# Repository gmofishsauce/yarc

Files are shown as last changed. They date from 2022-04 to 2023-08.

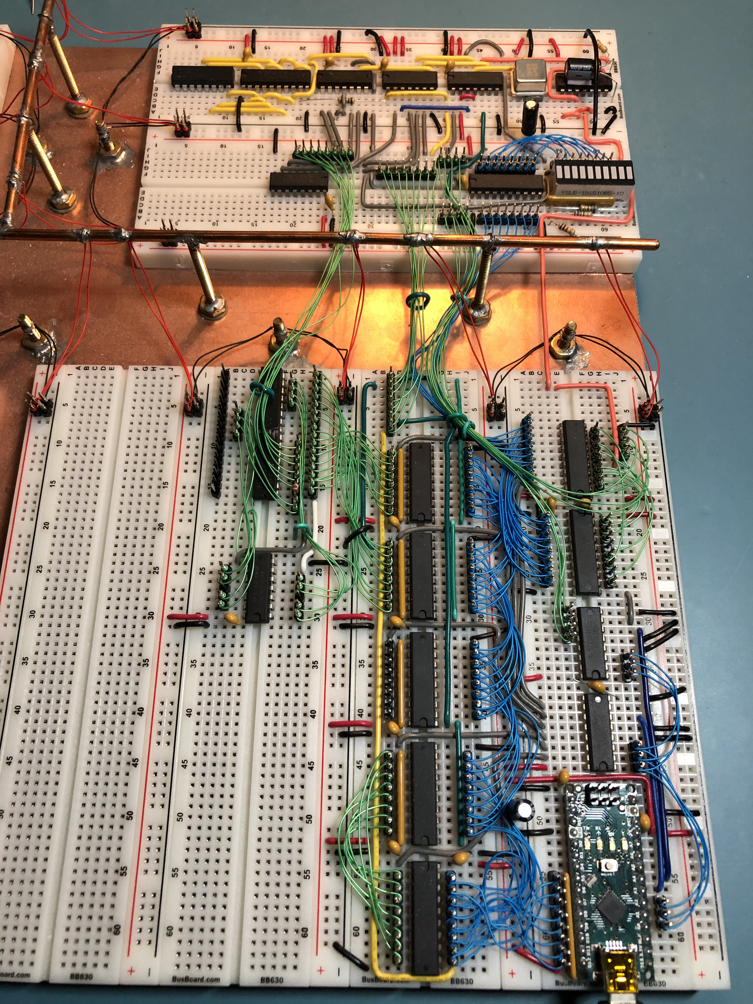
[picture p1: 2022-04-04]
img/2022-04-03/YARC-buildout-2022-03-31-2.jpg

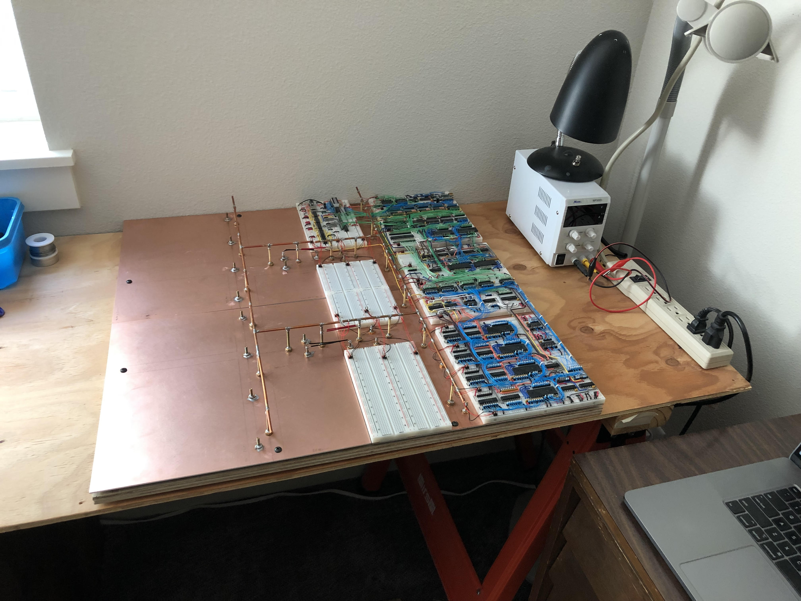
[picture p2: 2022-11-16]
img/2022-11-16/MechanicalCompleteOct13.jpeg

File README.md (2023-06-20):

# YARC - Yet Another Retro Computer

## Overview

YARC is a homebrew CPU and computer design implemented in a retro style.
Work on YARC started in April 2021. The initial concept was an 8-bit
computer with a 16-bit multiplexed address/data bus and extensive
pipelining.

In December 2021, the design changed to a 16-bit computer with separate
address and data busses, minimal pipelining, four general registers, an
8-bit-wide/2-cycle ALU, and two hardware stacks. In short, a general
register machine with specific concessions to the efficient implementation
of Charles Moore's FORTH programming language.

Most recently, I decided not to build the stack hardware and to instead
focus on developing the basic instruction set using two of the four
registers for PC and SP. I plan to write a translator for a small subset
of web assembler to YARC machine language (an "AoT" in their terminology,
ahead-of-time compiler). This will allow me to program the YARC in a small
subset any language that can target WASM--like Gnu C or Golang--rather
than confining YARC programming to the Forth language.

YARC is permanently tethered to a host computer (Mac) through a module
called the "Downloader" (a misnomer, because communication is supported
in both directions between host and YARC). The Downloader is based on a
modern microprocessor (Arduino Nano) which implements serial over USB.

The YARC itself is built from 74HC-series CMOS parts, with a few
out-of-period extensions like 8kx8 static CMOS RAMs.

## NRR - It's Not Really Retro

YARC's architecture resembles the [Data General Nova](https://en.wikipedia.org/wiki/Data_General_Nova) minicomputer. The Nova was introduced in 1969. YARC, like Nova, is mostly built from 7400-series components.

But the YARC is _nothing_ like a 1970s minicomputer. Why not? Let me count the ways...

* **Sophisticated open source design software.** In 1969, "design software" meant a sharp pencil, a [plastic template](https://www.amazon.com/Alvin-TD1279-Electric-Electronic-Template/dp/B000KNLR4A/ref=asc_df_B000KNLR4A/), and an angled table. Now, it means [KiCad](https://www.kicad.org/).
* **Highly integrated, sub-100ns static RAMs.** In 1969, semiconductor memory hadn't happened yet. YARC relies on 8k x 8 static CMOS RAMs with 55ns access times - each chip contains more transistors than an _entire_ Data General Nova. And the original Nova, with core memory, had a 5-microsecond cycle time - about 10x slower than YARC can likely achieve.
* **Universal knowledge base.** In 1969, knowledge about computer design was in the hands of a few experts. Today, a quick search can bring you [this](https://www.godevtool.com/GoasmHelp/usflags.htm) or [this](https://www.righto.com/2013/09/the-z-80-has-4-bit-alu-heres-how-it.html).
* **These aren't the 7400 series components you're looking for.** YARC is built with 74HC-series components. These have better noise margins, controlled edge rates, and far lower power consumption than traditional 7400-series TTL. It's fair to say the 74HC-series wasn't introduced until it was already obsolete!

## What's here?

### [ard](https://github.com/gmofishsauce/yarc/tree/main/ard/yarc_fw) - Arduino code for YARC downloader

Nano IDE (v2.X) project holding C++ code for the Arduino that implements
the "Downloader" (which should be renamed to "System Interface" or something).

### [doc](https://github.com/gmofishsauce/yarc/tree/main/doc) - YARC documentation

Engineering documentation for YARC. No "user documentation" is planned,
but some of the documentation is tersely user-oriented, such as the
document that describes the assembly language.

### [ftz](https://github.com/gmofishsauce/yarc/tree/main/ftz) - Fritz sketches for YARC.

Fritzing is a useful sketchpad for breadboard-based designs but it's
incredibly quirky.  No guarantees anyone will be able to load these
sketches, not to mention modify them.

Fritzing really, *really* wants everything in "``~/Documents/Fritzing``" on
Mac, and on Mac, setting $HOME does not affect the expansion of tilde.
But I found that making "``~/Documents/Fritzing``" a symlink into this repo
works.

### [img](https://github.com/gmofishsauce/yarc/tree/main/img) - Eye candy

Images of Fritzing sketches, KiCad schematics, and the implementation
itself. Allows the schematics and layouts to examined without
installing the apps (KiCad and Fritzing).

### [ki](https://github.com/gmofishsauce/yarc/tree/main/ki) - KiCad schematics

I started using KiCad just after 6.0 came out so if you use an earlier
version, you'll have to upgrade to load the sketches.

### [yarc](https://github.com/gmofishsauce/yarc/tree/main/yarc) - Host software

All the host software is written in Go and tested on darwin-amd64
(Intel-based Mac, not M1) only. The host software is contained in a Cobra
CLI defined here.

### [yasm](https://github.com/gmofishsauce/yarc/tree/main/yasm) - YARC microassembler and assembler source code

The YARC assembler supports definition of the assembly language
mnemonics within the language along with the microcode for each
instruction. So the code in this directory defines the YARC instruction
set.

The assembler itself is invoked by `yarc asm ...` in the host software.

## Problems with YARC

YARC is my first-ever large digital design. It has many issues.

### Messy Control Circuitry

The microcode (writable control store) and ALU (arithmetic/logical unit) of YARC are implemented with RAMs instead of the more common EEROM/EPROM technologies. The RAMs must be "downloaded" with content from the host (Mac) through the Arduino ("downloader") before YARC can start.

This is cool, as I can fundamentally change YARC's behavior without popping ROMs in and out of circuit. But it greatly complicated the design, requiring a "back bus" for writes to ALU and Microcode RAM, additional transceivers, and control circuitry. I made matters much worse by failing to think through the control circuitry in a unified way, instead constructing a bunch of special-purpose control registers.

### Floorplanning Issues

YARC is implemented on 32 large solderless breadboards mounted to four 1' square copper clad boards. At 2' by 2', it has the potential for very long wire runs. I made this situation far worse than necessary by putting controls distribution in the center rather than centralizing data buses and bus transceivers and bringing control signals in from the edges.

### Write timing

Both the main memory RAMs and the 74HC670 devices used for the dual-ported general registers suffer from issues if their address inputs change while their write-enable signals are active (low in both cases). I conceived each bus cycle as "outputs are enabled during first half of clock with clock high, enables go low for second half of clock, and writes are latched at rising edge". Unfortunately, transceivers enables are "enables", and also drive address lines; so their settling time overlaps with the write signal going low. I had to implement delay lines for write clocks in two places.

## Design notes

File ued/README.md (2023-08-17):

# Microcode editor

The original microcode editor is in first.htm. It "works".

A prototype "improved" microcode editor is in ucode.{htm,js,css}. It's not ready.

## Usage

Open the `.htm` file directly in the browser. The page does not use the network and does not write any local state. As you set the controls, the text at the bottom of the screen changes. When you are satisfied, copy and paste that text into Arduino C code or yasm source code. Refresh the page to reset.

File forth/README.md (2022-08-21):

# Forth

The goal of YARC is to eventually bootstrap Forth on the YARC,
using the approach called "subroutine threaded code with in-line
expansion" but with 30 or more basic Forth primitives implemented
as machine instructions, i.e. in microcode.

This is similar to https://www.jhuapl.edu/Content/techdigest/pdf/V10-N03/10-03-Lee.pdf.

A beautifully-commented Forth implementation for x86 Linux can be
found in the jonesforth directory. Of course I won't need to define
the primitives (DUP, SWAP, and about 30 others) in assembly language,
because they'll be single machine instructions implemented in yarc/yasm.
And I won't need e.g. **next** as a primitive either; it will simply
be a YARC instruction fetch, as the Forth "inner interpreter" will be
the instruction fetch hardware of YARC.

But Jonesforth will guide the set of words that have to be implemented
in assembler (there will be some, such as the words that handle console input)
and the Forth file may be consumable directly if I can fully duplicate the
functionality of the jonesforth.s file in YARC.

Nevertheless, YARC will remain a general register computer with a
standard assembly language and have only certain concessions to the
Forth implementation. The concessions include the two hardware stack
and the microcoded primitives.

YARC is similar to http://users.ece.cmu.edu/~koopman/stack_computers/sec4_2.html.

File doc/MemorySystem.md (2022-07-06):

# YARC 30k RAM

## System Context

The YARC data and address busses have 16 wires. There are 16 data bits and
15 address bits. The high-order "bit" on the address bus is the READ/WRITE#
signal. The only other global control signal is the clock; unlike other
parts of YARC, the memory system's behavior is does not vary between init
and runtime (i.e. the YARC/NANO# signal plays no part in memory control).

The 32k address space is divided into 30k bytes of memory and 2k bytes of
I/O space. The memory is implemented with 4 8kx8 CMOS static RAMs. These
are not "period" parts ("It's Not Really Retro!"). Each RAM contains about
400,000 transistors. Such parts became available in the 90s as geometries
fell below 1 micron (1000nm).

The high-order address bit is ignored, so the address 0x8000 folds back
to address 0, 0x8001 to 1, ... and 0xFFFF to 0x7FFF.

Control logic is implemented using 74HC-series MSI like the rest of the YARC
design. 

## Functionality

Memory is both byte and word addressable. Three types of memory cycles are
supported: byte on even address, byte on odd address, and word (16 bits)
on even address. The behavior of word cycle on odd address is undefined.

Memory responds to the addresses 0x0000 through 0x77FF ("30k - 1"). Addresses
from 0x7800 to 0x7FFF do not select any of the RAM chips nor open the
memory bus transceivers. If the I/O subsystem doesn't decode the address,
the data bus will be undriven. The resulting behavior is undefined but in
practice the implementation returns 0xFFFF for reads and discards writes.

## Implementation

Refer to the KiCad schematic title "YARC Memory" or the equivalent image
in the **img** directory.

Fundamental control signals are developed by the NAND gate U14A and the
decoder U22A. These are found at coordinates B1 in the schematic. The NAND
gate's output is `RAM/IO#`. This is low for I/O addresses (0x7800 through
0x7FFF) and high for memory addresses (0x0000 through 0x77FF).

Decoding this signal with the `READ/WRITE#` line (`SYSBUS:15`) (section B1)
produces the four signals `MEMRD#`, `MEMWR#`, `IORD#`, and `IOWR#`. These
are unclocked and as a result are potentially glitchy.

The IO read/write signals are not used by the memory subsystem, although
`RAM/IO#` and a signal called `LOW128#` (derived from the address bus in
section C1 of the schematic) are generated on-board and routed to a decoder
in the Downloader Extension.

MEMRD# and MEMWR# are mixed with the clock to create the signals `MEMRD_CLK#`
and `MEMWR_CLK#` (section B2). These are not (supposed to be) glitchy, since
the address shold have settled before the clock goes low in the second half
of each cycle. (Normally, we don't use an overbar or `#` symbol for clock
lines; maybe we shouldn't here either.)

The clocked MEMRD and MEMWR signals form the output enable (OE#) and
write enable (WE#) signals to the RAMs. The RAM/IO# line is used for the
active-high CE2 line.

The low chip-enable is used to select the correct
RAM (or RAM pair for 16-bit operations). This the result of somewhat
complex decoding performed by half a 2-4 decoder (139) U22B and by U26,
a multiplexer, found in C2 and C3 of the schematic. The results are the
four signals `SEL_xRxB` where `x` is H for Hi or L for low. The range
refers to the address (upper or lower 16k) while the byte refers to
high byte or low byte.

The 157 is switched based on the 16-bit cycle line `MEM16#` so that
two RAMs are selected when `MEM16#` is low but only one RAM when high.
The bus transceivers, in turn, are controlled by signals derived in
D1 through D3 of the schematic. The `CROSS_EN#` signal enables the high
memory bus to low system bus when a byte cycle is performed to an odd
address. `STRAIGHT_EN#` enables high-to-high and low-to-low transceivers
for both even-addressed cycle types, byte and word.

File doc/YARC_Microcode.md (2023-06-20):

# YARC Microcode

## Overview

YARC is a homebrew 16-bit microcoded computer. When the Arduino-based control processor ("Downloader", "the Nano") enables YARC execution, one word of microcode is clocked from the writeable control store (WCS) to the microcode pipeline register "K" on each rising edge of the system clock. The value in the K register drives control lines to all parts of YARC.

The WCS and K register are are organized as four byte-wide "slices". The transceivers that connect them to the system bus are under control of the Nano only, so YARC cannot update its own control store. The Nano typically initializes the WCS by writing values transmitted from the host (Mac) computer. Microcode is authored on the Mac and transformed into download format by an assembler. The assembler allows the YARC's instructions to be defined (by authoring the microcode for each one) and then used, i.e. it is both a microcode and instruction set assembler. It is described in a separate file in this directory. The Nano can also write directly to the K register, allowing it to control all parts of YARC for testing.

YARC has 16-bit instructions. The current instruction is stored in the dedicated register IR which is made up of high and low bytes IRH and IRL. Instructions in the range 0x0000 through 0x7FFF are jumps and calls; these are not microcoded and will be described later. Microcoded instructions range from 0x8000 through 0xFFFE. The high-order bit is always 1 (in effect it selects microcoded instructions versus hard wired jumps and calls). The 7 remaining bits of IRH form address bits 12:6 of the WCS address. A six-bit synchronous binary counter forms address bits 5:0. The counter is reset to 0 when IR is loaded and only counts up. So there are 2^7 = 128 distinct opcodes, each of which may execute for up to 2^6 = 64 clock cycles.

This describes the entire microcode controller: every instruction executes 1 to 64 microcode words in order. There are no microcode branches or loops. The way conditional flow control instructions are executed is described later. 

Each 32-bit word in the WCS is called a "slot". Within a machine instruction, each slot represents one clock of execution. Each instruction must end with the microcode steps to fetch the next instruction and clock its first word into the K register, so in effect each instruction can have only 62 useful steps. Most instructions are much shorter. The 8-bit wide ALU requires two cycles to perform a 16-bit logical or arithmetic operation, so the instruction ADD R0, R1, R2 requires four clocks: ALU phase 1, ALU phase 2, FETCH, and DECODE, after which the next instruction will execute microcode from slot identified by IRH defined by whatever was FETCHed.

The large number of slots (64) available to each instruction is mostly an artifact of the unrealistically large size of available memory chips (8k x 8 being the smallest widely-available part still in production in 2022). The large number of slots will, however, allow for some interesting instructions, such as a 16-bit multiply.

## Writing Microcode

Microcode authoring is supported by a simple single-page web application found in yarc/ued/first.htm. This file is intended to be opened locally rather than served by an HTTP server. I am neither a Javascript programmer nor a web developer. The code in `ued` is mostly copied from bits and pieces found on Stack Overflow.

As the controls are used to alter the values of fields, the commentary lines at the bottom of the page will update to display the field values. These text lines can be copied and pasted into YARC assembler (yasm) source files, typically into `.set` directives. Other plausible functionality, such as pasting microcode into the page to disassemble hex to field values, has not been implemented.

## Microcode Fields

The microcode is described as a set of bitfields in the 32-bit K register. The Nano must write it in 1-byte wide slices, however, so for sanity the design tries to break up the microcode into byte-wide chunks with somewhat meaningful field groupings.

All bits that are not decoded as fields are active LOW. Multiple bit fields either reserve the "all 1s" value as no operation or are enabled by some active LOW bit. The end result is that 0xFF_FF_FF_FF implements "no operation" if executed as microcode. The Nano initializes all of microcode memory to this FF pattern during YARC power on and writes this same pattern to the K register to make the YARC "safe" (inactive).

### K[3] Register Control Word

K3 (the most significant bits of K) are the Register Control Word (RCW). Note: the RCW was previously called the Register Specifier Word (RSW) and is still called that in many places.)

This word specifies the behavior of the two ALU source busses and the ALU destination bus.

```
.bitfield src1   31:30   # contains a gr
.bitfield src2   29:27   # contains a gr (3..0) or a constant reg (7..4)
.bitfield dst    26:24   # contains a gr (3..0) or a conditional gr (7..4)
```
The src1 field (2 bits) specifies one of the four general registers. The specified src1 register also drives the address bus.

Src2 (3 bits) may be one of the four general register 0..3 or, by specifying a value in the range 4..7 may be one of the small constants -2, 1, 1, or 2. These constants support "auto increment" or "auto decrement" addressing; e.g. the instruction MOVBI (R0), +1, R2 can address memory at R0 and clock the data into R2 during the first cycle, while simultaneously performing ALU phase 1 of ADDing R0 and +1. The next cycle can perform ALU phase 2 and clock the result back to R0.

The correspondence between src2 values 4..7 and small constants is:

```
.set const_p2 4   # 4 in src2 makes the value positive 2 (p2)
.set const_p1 5   # 5 makes the value positive 1 (p1)
.set const_n2 6   # 6 makes the value negative 2 (n2)
.set const_n1 7   # 7 makes the value negative 1 (n1)
```

The dst field may specify a general register 0..3 or, by specifying a value in the range 4..7, may specify a _conditional load_. During a conditional write, four bits specify one of 16 conditions (carry set, overflow, etc.) from the ALU flags. The write occurs if the condition is satisfied, and otherwise does not occur.

Since one of the four "general" registers must act as the program counter, a microcoded ADD followed by a conditional load to the PC general register (R3) is used to implement conditional branches.

The four bits that select the branch condition are called the ALU Condition Nybble (ACN). During an ALU operation, these same four bits select one of 16 ALU operations. Both the RCW and the ACN may come from either microcode or from the instruction register (IR). The decision is made on a cycle-by-cycle basis under the control of control bits in the K[0] microcode word, described below.

Note: The register implementation can read two register and write one in each machine cycle, but the microcode programmer must not read and write the same register in any one cycle. This is due to a limitation of the components and is not detected in hardware. Because of the serendipitous decision to implement an 8-bit, 2-cycle ALU, this restriction has less impact than might be imagined. The instruction ADD R0, R1, R0 is implemented by reading R0 and R1 during the first (ALU phase 1) cycle and writing the sum to R0 at the end of the second (ALU phase 2) cycle, so it does not violate this restriction. A single-cycle like MOV (R0), R0, which would read an address from R0 and write data back to it at the end of the cycle, is forbidden.

### K[2] ALU Controls

```
.bitfield acn           23:20   # 1 of 16 alu operations
.bitfield alu_ctl       19:18   # 0=alu_phi1, 1=alu_phi2, 2=alu_in, 3=none
.bitfield alu_load_hold 17:17   # when low, clock the port 2 ALU holding register
.bitfield alu_load_flgs 16:16   # when low, clock the flags (ALU phi2 or write to flags)
```
The ALU operations (ACN described above) are defined in the instruction set document: 0 is ADD, etc. The ALU control field specifies ALU phase 1 or 2 or no operation. The value `alu_in` reverses the src2 transceivers to the data bus allowing a microcoded move the src2 holding register. This is encoded as an ALU operation to prevent combining it with either ALU phase 1 or 2 (the data would arrive too late in the cycle to allow the ALU to work). The pipeline register is "non-architectural", i.e. it is not exposed in the instruction set.

The `alu_load_hold` bit causes the ALU holding register on the src2 bus to be loaded. This must be a separate, microcode-programmer controlled bit so that the microcoder may issue ALU phase 1 with a load (for a register to register operation), or, alternatively, may do an `alu_in` cycle to load the pipeline register from memory, then an ALU phase 1 that operates on a register specified by src1 and the preloaded pipeline register.

Finally `alu_load_flgs` bit causes the flags register to be loaded. It is normally set during ALU phase 2, but would not be set for e.g. the add that updates the PC (R3) on every FETCH/DECODE. It must be set to load the flags from memory (e.g. MOV ..., F or POP F, etc.)

### K[1] Busses and Stacks

```
.bitfield sysdata_src  15:13  # 1 of 8 data bus drivers
.bitfield reg_in_mux   12:12  # register input, 1 = sysdata, 0 = alu output
.bitfield not_used     11:9   # reserved
.bitfield dst_wr_en     8:8   # enable write to GRs
```
The `sysdata_src` field identifies the subsystem that will drive the data bus in this cycle, if any. Note: the address bus is always driven by the general register selected by the src1 field.

```
# data bus drivers for memory writes
.set bus_gr    0        # general register drives bus
.set bus_sp    1        # not used (was: hardware stacks)
.set bus_ir    2        # instruction register drives bus
.set bus_f     3        # flags register drives bus
.set bus_mem   4        # memory drives bus (memory read)
.set bus_tbd_5 5        # unused
.set bus_tbd_6 6        # unused
.set bus_none  7        # "none" - permanently reserved
```
The next bit determines whether data for a register write, if any, comes from the ALU outputs or the system data bus. The next three bits are reserved. Finally, the LS bit of K1 enables writes (including conditional writes) to the general registers. If the bit is high, no write will occur. If the bit is low and the dst bits in K[3] specify a register, that register loaded. If low and dst specifies a conditional load, that register will be loaded if the condition specified by the ACN is true. The mapping of conditions to ACN values can be found in the instruction set document.

### K[0] Miscellaneous Controls

```
.bitfield rw            32    7:7   # read/write# line for all memory and I/O transfers
.bitfield m16_en        32    6:6   # enable 16-bit memory or I/O cycle (default 8 bit)
.bitfield load_ir       32    5:5   # clock the IR
.bitfield rcw_ir_uc     32    4:4   # RCW from IRL7:0 when low, from K31:24 when high
.bitfield carry_en      32    3:3   # Force carry-in low when low (for add vs adc)
.bitfield load_flgs_mux 32    2:2   # From sysdata when high else from ALU result flags
.bitfield acn_ir_uc     32    1:1   # ACN from IRH11:8 when low, from K23:30 when high
.bitfield ir0_en        32    0:0   # Force IR:0 to sysdata low when low (for jumps)

```
The MS bit specifies read or write for transfers to the memory and I/O space only; if the instruction specifies (e.g.) a load of the instruction register IR, the bit is not regarded. The `m16_en` bit enables 16-bit memory accesses; when high, all memory access are bytes. Note: byte accesses may be to any address, but 16-bit words may be read or written from even addresses only. The effect of a 16-bit access to an odd address is not defined. The error is not detected by hardware.

The `ir_clk` bit enables writes to the instruction register. It must be low during a cycle that fetches the next instruction. It could be used to support a hypothetical `execute` instruction that would execute an instruction out-of-line.

The `rcw_ir_uc` bit selects the source of the RCW, from K[3] when high else from IRL.

Review: in any given cycle, both the Register Control Word (RCW) and the ALU Condition Nybble (ACN; 12 bits total) can come from one of two places: (1) from the microcode bits in K3 and the upper bits of K2, or (2) from the IR bits 11:0. This design is an expensive compromise (3 multiplexer chips and a bunch of wires) between (1) having a relatively small number of instruction bits and (2) wanting to enable complex, multiple-step microcode instructions that may perform arithmetic. The first requires the that low byte of the instruction register be able to specify registers, and the second requires that the microcode be able to do so (since the instruction bits won't change during a complex instruction that may need to do various register and arithmetic operations).

The four low-order bits of K[0] are described in their comments.

## Jumps and Calls

The low-numbered even opcodes 0x0000 through 0x7FFE are CALL instructions that target themselves: the opcode 0x0020 is CALL 0x0020. Since instructions are 16-bit values and all 16-bit values must be read from even addresses, the odd numbers 0x0001 through 0x7FFF would not be useful as similar instructions. So the hardware maps the patterns as JUMPs (rather than CALLs) to next-lower opcode value: the opcode 0x0021 is JUMP 0x0020.

The high-order bit of IR is connected to the control line of a multiplexer. When it's 1 (instruction 0x8000 through 0xFFFF), the multiplexer gates the 7 low-order bits of IRH through as microcode address bits 12:6. When it's a 0, the multiplexer gates through a fixed pattern, which is 0b111_111X with X = 0 for calls and 1 for jumps. The effect is that all jumps and calls are transformed in the opcodes 0xFFxx and 0xFExx. Microcode at these locations pushes the PC on the stack (for calls) and then loads the instruction register into the PC, masking the low order to ensure the next fetch is from an even address. When loading the PC, bit K[0]:0 should be low to force the low order bit of the instruction, which is its own target address, to be 0.

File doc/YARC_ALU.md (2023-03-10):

# YARC ALU

## Overview

The YARC is a 16-bit retrocomputer implemented with 74HC-series CMOS versions of 1970s style components but using more modern 8k x 8 RAM chips (because 1970s RAMs have become serious collector's items). It has a 16-bit data bus, 16-bit-wide main memory, and a small 32k address space. 30k of the address space is RAM (0 - 0x77FF) and the top 2k is reserved for I/O registers.

In order to reduce part count, YARC's ALU is only 8 bits wide. Two clock cycles are required for each ALU operation, including the program counter increment following an instruction fetch.

There is lots of precedent in early computers for ALUs that are narrower than the system data bus or memory width. The Z-80 had an ALU only 4 bits wide. Digital's 12-bit PDP 8-I had a 1-bit ALU; it required 12 clock cycles for an add, a subtract, etc. The RCA 1802 microprocessor also had a 1-bit ALU and required 8 clock cycles for a byte operation. Early calculator chips generally operated on one BCD digit at a time.

This document describes the YARC ALU in detail. Refer to sheet 15 (YARC ALU) of the YARC's KiCad schematic for the wiring of the ALU buses. Refer to sheet 17 (YARC ALU Controls) for the flag logic (how the zero and carry flags are set) and to sheet 11 (YARC Flag Logic) for how the CPU flags are interpreted by conditional branch instructions.

## ALU Control

The ALU is controlled by a decoded two-bit microcode field. When the field's value is 3 (0b11), the ALU performs no operation. When 0, the ALU performs a first-cycle ("phi1") operation and when it's 1, a second-cycle ("phi2") operation. The effect of the value 2 (0b10) is explained later.

The ALU has two 16-bit input holding registers, one for each "side". The holding register on ALU port 1 is clocked on any phi1 cycle (i.e. at the start of any ALU operation). Separate bits control the loading of the holding register on ALU port 2 and loading of the ALU flags register. A separate 4-bit field selects one of 16 possible ALU operations. This field must be set to the desired operation during both phi1 and phi2. The operations are typical ALU operations (ADD, SUBTRACT, bitwise operators). They are defined in the accompanying instruction set document.

## ALU Input

The holding registers, which are shown on sheet 11 (YARC Flag Logic), are "fed" from the YARC's general registers via buses S1BUS15:0 and S2BUS15:0. The YARC has 4 16-bit general registers, one of which must be reserved as the PC. The registers support two independent reads per clock cycle. One bank feeds the S1BUS and the other bank feeds S2BUS. The registers to read are called out by separate microcode fields. The content of S1BUS is also driven to the system address bus in all cycles.

The input holding registers drive *byte wide* inputs to the ALU core called A and B. These must each supply one operand byte per cycle: the low operand bytes during phi1 and the high bytes during phi2. Thus the input registers thus act as 16:8 multiplexers. Each holding register is implemented as two 8-bit halves with separate enables. Both low bytes are enabled to the ALU "A" and "B" inputs during phi1, both high bytes during phi2.

The lower byte of both holding registers are implemented as transparent registers (like the popular 74LS373; actually CMOS 74HC573s which have nicer "straight across" pinouts). During the cycle, their outputs follow their inputs with a delay of about 25ns. At the end of the cycle, they "freeze" (latch) the value. The high byte of both holding registers is implemented with clocked D registers (HC574s). Both parts have 3-state outputs which are used to accomplish the multiplexing function.

This may be clarified by an example: instruction fetch. During a fetch cycle, the PC (say, general register 3) is selected on S1BUS. The microcode does not select a general register for S2BUS; instead, it selects one of the four "small constant" registers, the value "+2". The S1BUS is driven to the system address bus fairly early in the cycle. The microcode calls out phi1, so the low-order bits of R3 and "+2" are added during the cycle. This is possible because the low byte of the S1BUS/"A" holding register is transparent (it "flows through" to ALU's "A" input) and the S2BUS/"B" holding register does the same.

At the end of the phi1 cycle, the low transparent low byte byte registers freeze and the high byte registers, which are edge-triggered "D" latches, each capture the upper byte of S1BUS and S2BUS, respectively. In addition, the ALU output register captures the low byte of the sum of R3 and +2. At the same time, the result of the fetch is captured by clocking the special register IR (Instruction Register) which begins the decode of the next instruction.

In the next (instruction decode) machine cycle, the microcode calls out phi2, which gates the high-order D registers onto the A and B inputs of the ALU. The ALU does another 8-bit add and, at the end of the cycle, provides the result through a transparent '573 latch. The phi1 register and the phi2 transparent latch can be clocked into any one of the four general registers; in this case, of course, the result is clocked into the PC (R3 in this example). During this machine cycle, the decode (microcode lookup) operation took place, and at the end of the cycle the control signals corresponding to the first cycle of the newly-fetched instruction are clocked from microcode memory into the microcode control register K.

## ALU Flags

At this point, the astute reader may be thinking: you've completely botched this. What about carry in? And carry out? And for that matter, carry from the low half operation to the high half? And how are you going to compute the zero flag across the two cycles of a 16-bit ALU operation?

Good questions. In fact this isn't easy. After a little background, we'll take it one case at a time.

The ALU includes a conventional flags register, with bits 0:3 holding C, Z, N, and V (carry, zero, negative, and overflow). The register is clocked by a microcode bit, which is normally set during phi2 cycles (but need not be, allowing for ALU operations that don't alter the flags). The register is diretly connected to the inputs of the flag interpretation circuitry described later. It may be gated to the data bus to read the flags as data. Finally, the flags register may be set from the data bus, allowing for e.g. a POP FLAGS instruction and also for instructions to set and clear the flags.

### Carry In

Because the ALU takes 2 cycles to perform an operation, carry must be propagated unconditionally from the 8-bit phi1 partial operation into phi2. On the other hand, the carry into phi1 from the flags register must be conditional, based on a microcode bit, in order to allow both ADD (with no carry in) and ADC (with carry in) as specified in the instruction set document. Without this important programmer convenience, it's necessary to explicitly clear the carry flag to perform a "stand alone" add operation.

These operations are performed by the logic and flip-flop in the lower left corner of the ALU Controls schematic. The registered carry flag is first ANDed with PHI_1_PLS (pulse) which is high during phi1. The result is then inverted and ANDed with the microcode bit K3, carry enable. The result becomes phi1 CARRY\_IN. At the end of phi1, the 8-bit half carry from the ALU is clocked into a flip-flop by the rising edge of PHI\_1\_CLK. This becomes the CARRY\_IN signal during phi2.

### Carry Out

At the end of phi2, the carry value from the 16-bit operation is clocked into the flags register if enabled by microcode. The value comes directly from the ALU devices as explained later.

### Zero Flag

The ALU devices compute zero over their four-bit A and B inputs and provide it as an output as explained later. In each cycle phi1 and phi2, these outputs are ANDed to produce an 8-bit zero flag. This half zero is clocked into the other half of a 74HC74 flip-flop at the end of phi1 and this value is ANDed with the phi2 half zero flag during phi2, producing a result that is conditionally clocked into the flags register along with the carry out.

### Sign (Negative, N) and Overflow (V) flags

These are produced by the ALU devices and stored (or not) along with the carry and zero flags.

## ALU Core

### RAMs

The "ALU chips" are 8k x 8 static RAMs.

Let me say that again: the ALU chips are 8k x 8 static RAMs. How? Why? Let's do "why" first.

The CPUs of many "retrocomputers" (and of course the CPUs of many computers of the 1970s) used the ubiquitous 74181 4-bit ALU chip. But these devices haven't been manufactured in a long time and are becoming collector's items. Some are no doubt reaching the rising end of their reliability bathtub curves as well. I didn't want to go there.

Instead, I use RAMs. I happen to have selected 8k x 8 55ns static RAMs for the memory subsystems in YARC, because they are the smallest and simplest RAMs still in regular production. These devices contain about 375,000 transistors and become producible in the early 90s, long after computers designed the like the YARC had ceased to be viable. I use these RAMs for ALU chips.

How is this possible? Well, consider: a 74181 has four bits of "A" input, 4 bits of "B" input, 5 bits of control lines to specify the operation, and a 1-bit carry input. That's 14 input signals. An 8k x 8 static RAM has 13 address lines. I observed that the 5 control lines allow for 32 distinct operations, most of which are never used (and some follow-on parts, like the 74381, had fewer operation controls).

By allowing only 16 operations selected by four control lines, an 8k static RAM loaded with the results of 4-bit operations can now emulate a 74181, which contains about 75 logic gates. Better, it has 8 outputs, so it can produce a four-bit result and all four traditional flags for every input combination. The 74181 produces carry, an equality signals (A = B), and two additional signals called carry generate and carry propagate.

Of course, using RAMs has a cost. They have to be loaded with the correct content before the YARC has an ALU. Until that time, YARC cannot even execute instructions because it cannot increment the program counter! This is addressed by the system downloader, which can take control of YARC's bus and gain write access to the ALU RAMs (in addition to the microcode RAMs and main memory). The YARC's functional RAM (microcode and ALU) must be properly initialized before the downloader, an Arduino Nano, can release the YARC to execute instructions. The requirement for writing into the ALU significantly complicates the design.

### Carry Select Addition

My lookup-based ALUs doesn't produce carry generate or carry propagate outputs. This means I can't do what is called "lookahead addition" with these devices. So each device (i.e. the RAM for the high-order bits) must wait for the lower order RAM to produce a carry output, which is input as an address line to the high-order device. This is combinational and occurs within each of the phi1 and phi2 clock cycles, so it's likely to become a critical path in system timing.

This can be partially addressed by a scheme I called "Cheesy Lookahead Carry" (CLC) when I (re-)invented it in 2021. I had no illusions that I was the first to think of it at the time, and it turns out it was invented by an IBM engineer 60 years earlier. "My" design is now known as a carry select adder. It's based on the observation that selecting one of two possible results is faster than computing the result.

Instead of having one ALU RAM for the upper four bits, there are two. The first has its carry input (address line 8) wired to "0", and the second has its carry input wired to "1". They are both presented with the same operation and A/B input data (the upper nybbles of the operands) at the same time that the low-order ALU RAM begins working on the low nybble.

The carry **output** of the low order ALU RAM is connected to the output enable of one high-order RAM, inverted, and then connected to the other. The output enable delay is about 30ns shorter than the RAM access time, which reduces the time taken by the entire ALU path by more than 25%.

All three ALU RAMs, one low-order and two high-order, have the same content and are written in parallel by the downloader.

## ALU Output

The low-order byte of output is registered at the end of phi1. The high order byte passes through a transparent driver to the ALU input multiplexer, allowing the result to be stored in a general register at the end of the phi2 operation cycle. The result could be captured on a later cycle if not overwritten (I think).

## ALU Operations on Memory

In YARC, the design goal speed of 4MHz to 6MHz will probably not be realized because of signal quality issues associated with long buses and breadboards. Despite this fact, these goal clock rates are still used to condition the design. The clock period does not allow for data to flow in from memory, through the ALU during phi1, and be latched in the lower-half of the ALU result register.

Instead, a separate cycle must be spent fetching data from memory into the S2BUS ("B" side) ALU holding register. This register is clocked under the control of a separate bit. The S2BUS transceivers are reversed (inbound) when when ALU control field is 2 (0b10) to allow in the data from memory. This operation (loading the B side ALU holding register) is encoded into the ALU control field to prevent a simultaneous phi1 or phi2 ALU cycle (that would not get the correct result).

## ALU Initialization

The downloader (Nano) can take control of the YARC's buses and write data, typically data downloaded from the host (Mac), into the ALU RAMs. There is an ALU Control Register (ACR) with 5 defined bits 0..4 accessible to the Nano (but not YARC; as with microcode RAM, the YARC cannot update itself).

ACR:0 enables the outputs of the high-order, carry = 1 ALU RAM for reading. ACR:1 enables both the low-order RAM and the high-order, carry = 0 RAM to separate 8-bit buses. The buses each have a transceiver to sysbus, and these transceivers are enabled by ACR:2 and ACR:3, respectively. So the pattern 0b1010 will read the high-order, carry = 1 RAM, 0b1001 the high-order, carry = 0 RAM, and the pattern 0b0110 the low-order RAM. Finally, with the Nano in control, ACR:4 can be used to set the carry in address bit (bit 8) of all three RAMs. The low-order address bits must be clocked into the ALU holding registers and the high-order address bits supplied as the ALU operation (from either the instruction register or K register).

The direction signal on the transcievers comes from the Nano's READ/WRITE# bit (address bit 15) when the Nano has control. So the same logic can be used to write the RAMs with the output enables false (high). The write signal is provided by a pulse output from the Nano.

## Summary

The YARC ALU emulates a conventional 1970s minicomputer ALU using unconventional techniques. A possible follow-on project is the construction of an ALU from discrete N- and P-channel MOSFETs or even bipolar transistors.

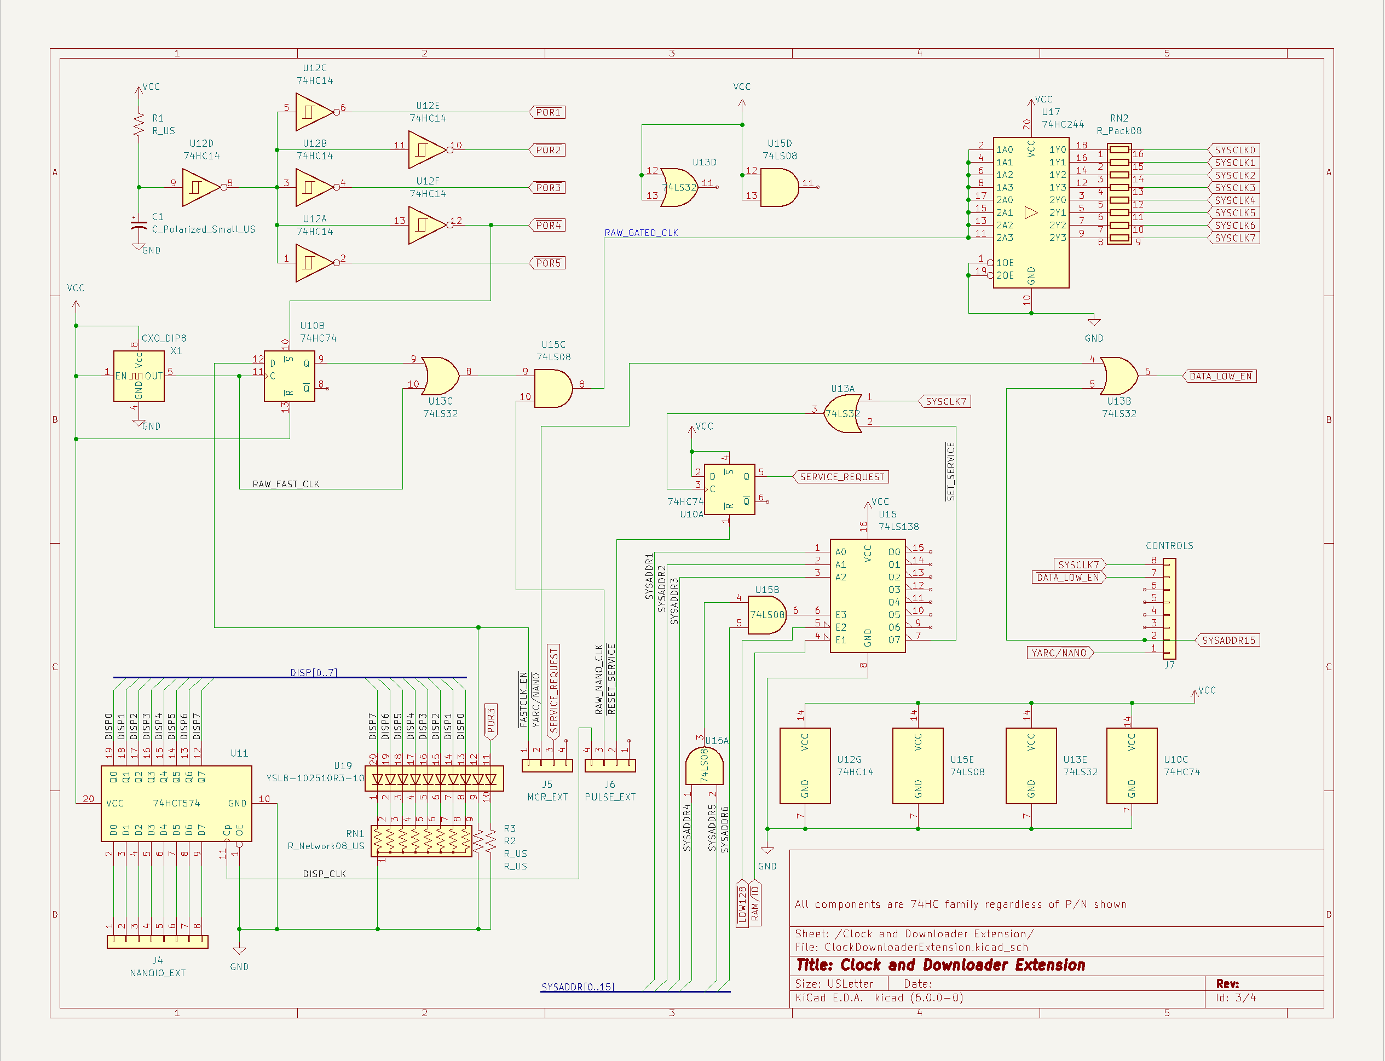
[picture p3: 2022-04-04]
img/2022-04-03/Clock and Downloader Extension Schematic.png

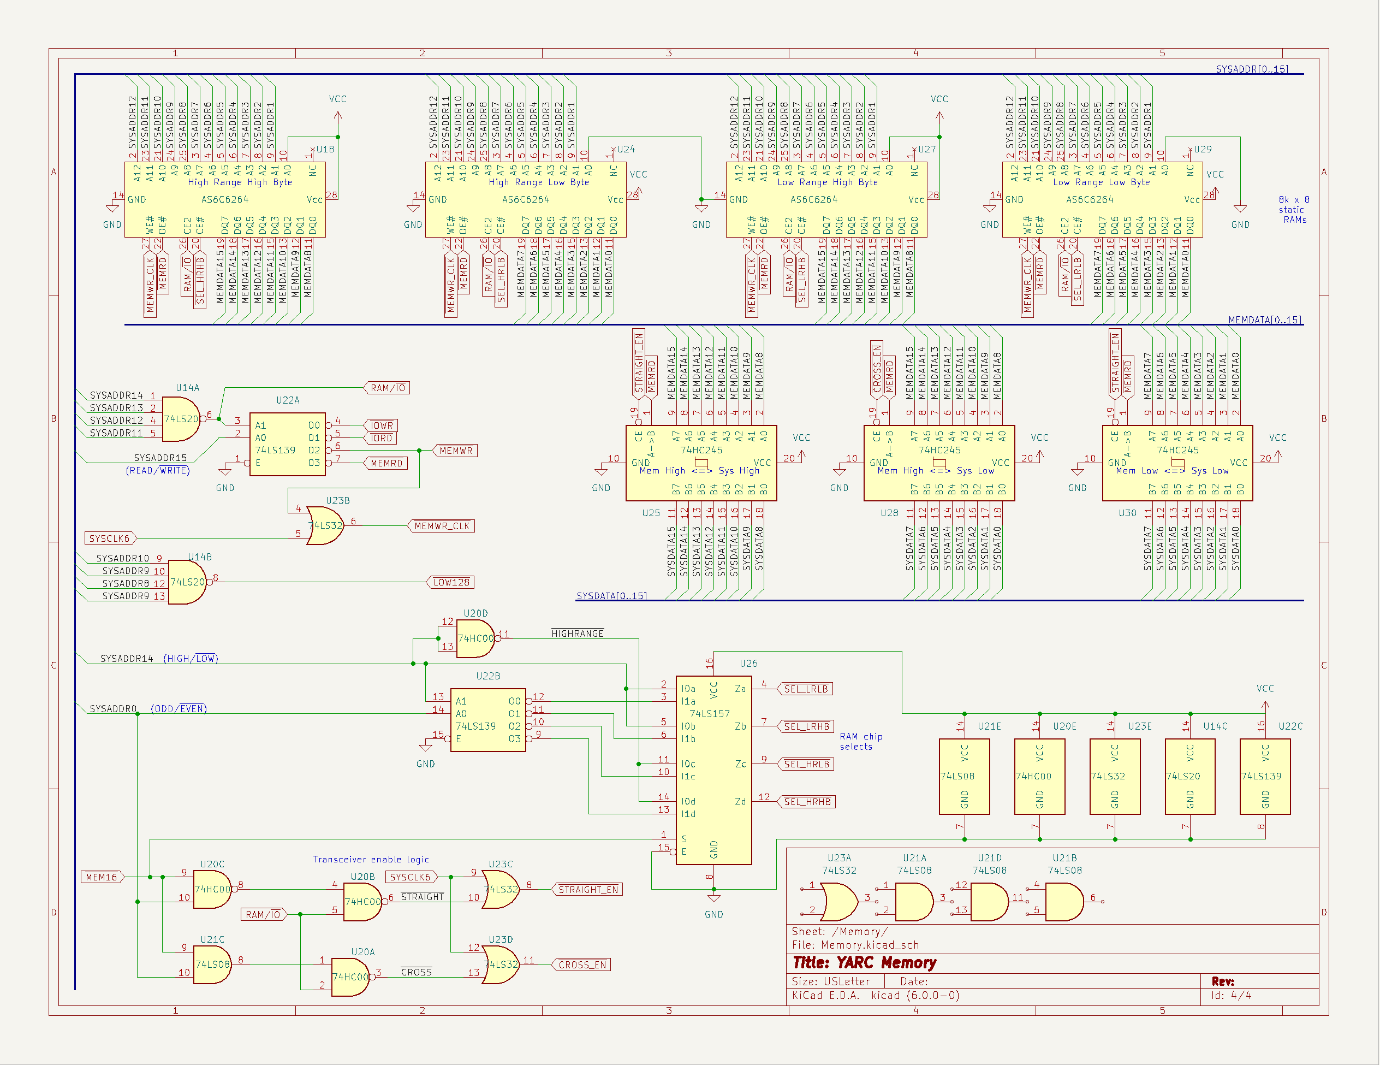
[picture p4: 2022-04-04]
img/2022-04-03/Memory Schematic.png

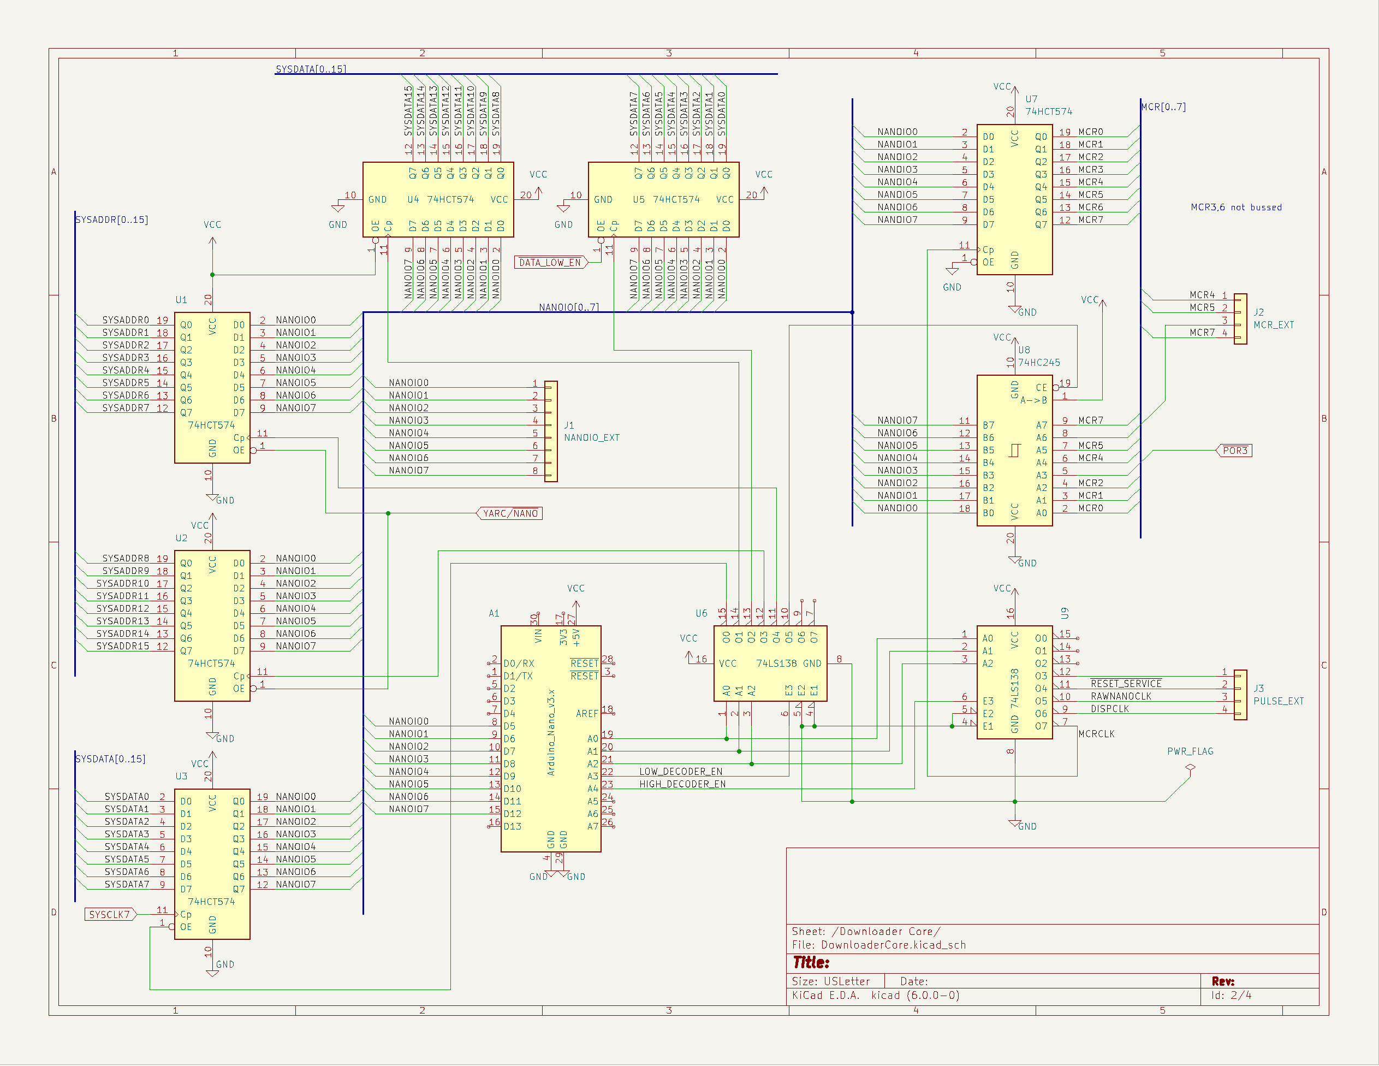
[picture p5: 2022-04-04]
img/2022-04-03/Downloader Schematic.png

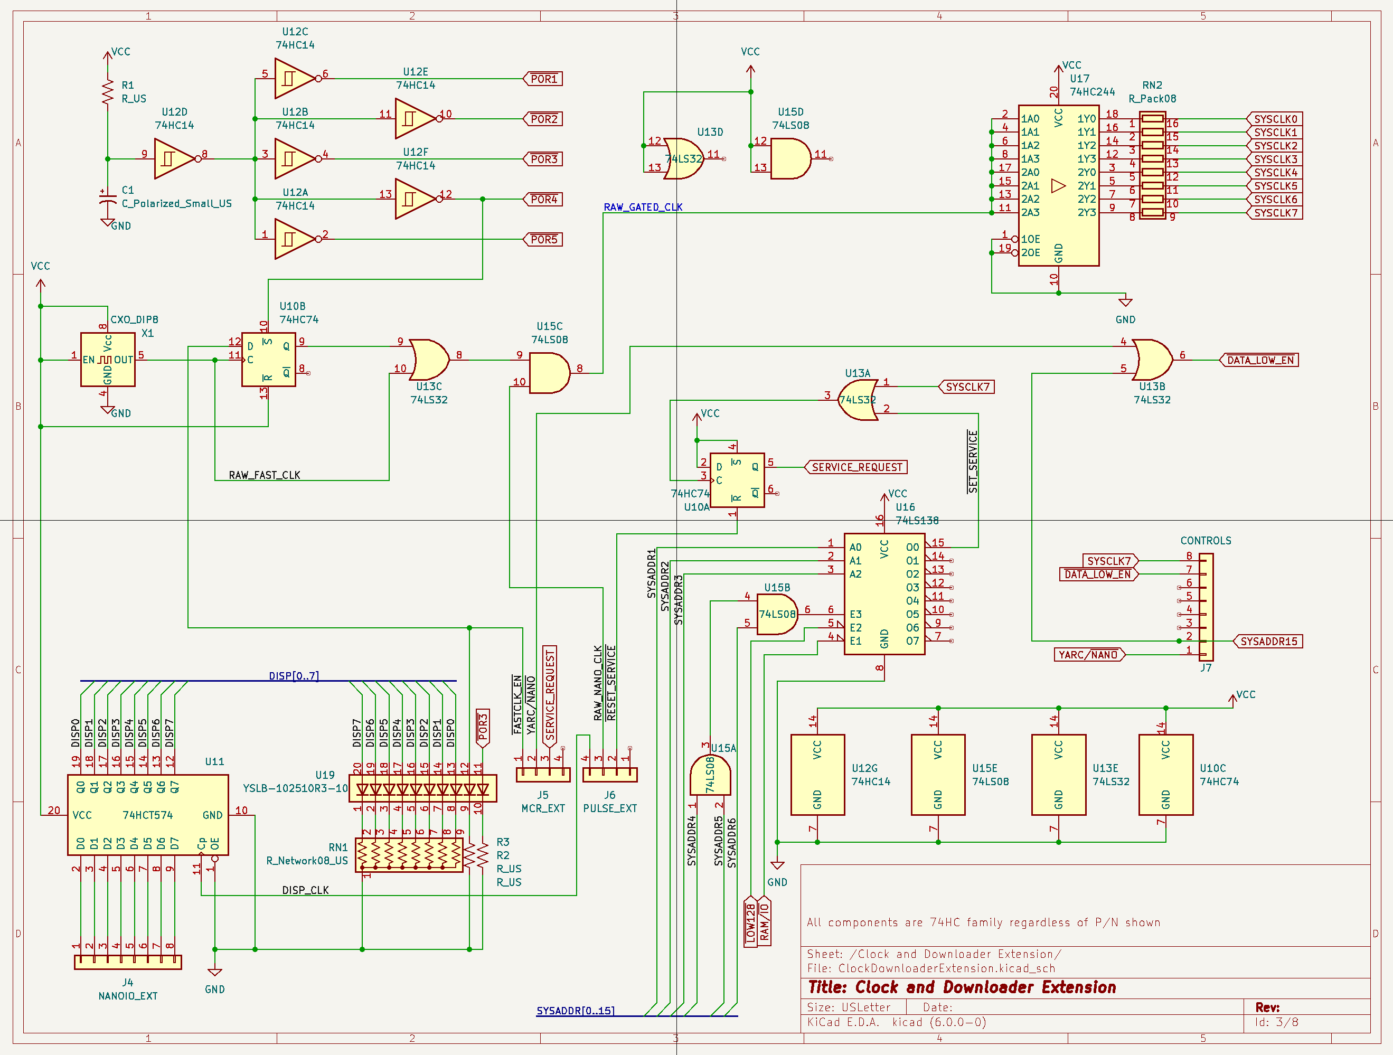
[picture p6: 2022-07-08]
img/2022-07-07/clock_downloader_extension_kicad.png

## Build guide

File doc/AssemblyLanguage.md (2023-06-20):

# YARC Assembly Language

## Overview

YARC assembly language ("yasm", like "chasm") is a combination microassembler
and assembler. The assembly language mnemonics are not built-in, but rather
defined, along with the microcode that implements them, using the language.
Once defined, they can be used for conventional assembly language programming.

The syntax is simple and rigid, requiring only a lexer. It is largely but
not strictly line-oriented. Each line (really "construct") begins with a
_key symbol_. A small set of key symbols are built into the language. These
"builtins" are used to define additional symbols, including additional key
symbols, in a sort of bootstrapping process that eventually providers a full
function assembler.

The language does not support constant expressions, so it does not even require
an expression parser.

The assembler (`yarc asm`) accepts a single source file on the command line.
The source may contain one or more `.include` builtins which specify additional
code by relative (to the main source file) or absolute paths. Source files have
the extension `.yasm` by convention. There is no linker; a successful run of
`yasm` results in the generation of a single, rigidly-structured binary output
file named `yarc.bin` in the current directory. This file
may be provided to the serial line monitor (`yarc host`) for download to YARC.

The assembler makes one full pass over the source code. Its design ensures it knows the absolute offset in the code stream at every point in time; as as result it can assign correct values to all labels during the source code pass. It cannot generate the code for forward branches to symbols it hasn't seen yet, so instead it generates _fixups_ which are placed in a _fixup list_. A lightweight second pass then processes the fixup list in order, correcting the opcodes and immediate values as required. This process is described in more detail under **Code Generation**, below.

## Builtin key symbols

All builtin symbols begin with dot (`.`), and dot may not be used in symbols
defined by the programmer. Programmer-defined symbols consist of a letter or
underscore followed by letter|digit|underscore. Values may be decimal numbers,
hexadecimal (0x) numbers, or strings delimited by double quotes. All currently-
defined builtins are key symbols.

### .set

```
.set symbol value
```

Substitue `value` when `symbol` is encountered in the source text. In order
to avoid some of the complexities of generalized macro processing, the value
may not contain a dot ("."). This prevents builtins in the expansion text.

The values may be numbers or strings. Initially, string values are intended
for one purpose only: sequences of "bitfield = value" expressions that will
be expanded within the `.slot` builtin described later. Examples:

```
.set RSP 5
```

Allows "RSP" to appear as value in a bitfield, while

```
.set FETCH "F1=1 F2=7 F3=0 F4=RSP"
```

allows "FETCH" to appear as the value or partial value of a `.slot` builtin,
providing a shorthand for often-repeated microcode field settings in the slot.

### .include

```
.include "path"
```

Include the file identified by the path. Paths are relative to the main
source file's directory or may be absolute.

### .bitfield

```
.bitfield name wordsize bitrange
```

The wordsize must be a power of two. The bitrange has the form i:j where
i and j are nonnegative integers with i >= j and both less than (wordsize - 1).

Example:

```
.bitfield src1 8 7:5
```

Specifies a 3-bit field containing the most significant bits of an 8-bit value.

### .opcode

```
.opcode name opcode nargs arg0 arg1 ... argn-1
.slot ...
.endopcode
```

Define an opcode. The name becomes a key symbol, the opcode's assembly
language mnemonic. The opcode is a value between 0x80 and 0xFF
conventionally written in hex.  The arg names must have been defined in
`.bitfield` directives already seen by the assembler (no forward references).
These define the content of the low-order byte of the instruction; when the
mnemonic is later written, the actual argument values must be compatible
with the bitfield sizes.

The `.opcode` builtin is followed by 1 to 64 `.slot` directives that define
the microcode for the instruction. The slot definitions are terminated by
a `.endopcode` builtin.

### .slot

```
.slot Field1=Value1 Field2=Value2 ...
      FieldN=ValueN ... ;
```

The `.slot` builtin is used to define a single 32-bit microcode word that
occupies one "slot" in the 8k x 32 microcode RAM. The field names must
previously have been defined by `.bitfield` directives with a wordsize of 32.
Values must be compatible with field sizes. The `field=value` expressions
may span lines. The slot must be terminated with a semicolon.

### .endopcode

```
.endopcode
```
Ends an opcode definition (sequence of slot definitions)

### .dup

Duplicate the microcode for an existing instruction as another (new) instruction with a new name and opcode. This is particularly useful for instructions that take control bits from the instruction register, e.g. ALU operations.

```
.opcode add 0x80 3 .src1 .src2 .dst
.slot "K3_NONE ALU_PHI1_K2 K1_NONE ALU_PHI1_K0_NO_CARRY" ;
.slot "K3_NONE ALU_PHI2_K2 ALU_PHI2_K1 ALU_PHI2_K0" ;
.slot FETCH ;
.slot DECODE ;
.endopcode

.dup sub  0x81 add
```

Duplicate the microcode for `ADD src1, src2, dst` as `SUB src1, src2, dst` in the microcode slots for opcode 0x81. Since the source, target, and destination come from the instruction rather than the microcode and the ACN is the `1` in `0x81`, this is all that's required to specify `SUB`.

## Labels

Labels are valid symbols terminated with a colon character `:`. They are equivalent to `.set theSymbol <location>` where location is the current offset in the code being assembled. 

## Code Generation Metasymbols

The assembler must know how to generate the bits for various instruction formats. This is accomplished by using builtin symbols in `.opcode` definitions; an example (`.src1`, etc.) can be seen in the code just above.

Each of these builtins results in creation of a _fixup_ that is placed in the _fixup list_ during the lexer pass. The fixup's code tells the assembler how to align a bitfield when generating an instruction. When an `ADD` instruction is used, for example, the assembler code behind `.src1` will cause the value to be collected, range checked (it must fit in a 2-bit field), and then aligned appropriately in bits 7:6 of the instructions low byte (which will be the RCW, assuming the microcode correctly specifies that the RCW should come from the instruction register in that cycle).

The available metasymbols are:

| Symbol | Compatible value | Meaning |
|---|---|---|
|.abs | Label | the entire opcode is replaced by the 16-bit value of the label |
| .rel | Label | the low byte of the opcode is replaced by offset from the instruction to the label |
| .immb | 8-bit value | the low byte of the instruction is replaced by the value |
| .immw | 16-bit value | the word following the instruction will contain the value |
| .rt | value in 0..3 | bits 1:0 of the high order byte of the opcode are replaced by the value |
| .src1 | value in 0..3 | bits 7:6 of the low order byte of the opcode are replaced by the value |
| .src2 | value in 0..7 | bits 5:3 of the low order byte of the opcode are replaced by the value |
| .dst | value in 0..7 | bits 2:0 of the low order byte of the opcode are replaced by the value |

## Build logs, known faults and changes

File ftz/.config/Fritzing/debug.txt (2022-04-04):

candidate:/Applications/Fritzing.app/Contents/MacOS
candidate:/Applications/Fritzing.app/Contents/Resources
data folders found: /Applications/Fritzing.app/Contents/Resources
translation en_US loaded 1 from /Applications/Fritzing.app/Contents/Resources/translations
registering font family: Droid Sans DroidSans
registering font family: OCRA OCRA
got transaction
referenceModel::loadAll completed
parts count 2188
load something
checking for backups
check files to load 0
create empty sketch
loading bin 'Core Parts'
module id mystery_part_sip_3_100mil not found in database
module id generic_ic_dip_8_300mil not found in database
module id generic_female_pin_header_2_100mil not found in database
module id generic_shrouded_pin_header_10_100mil not found in database
module Mystery Part - 3 pins:mystery_part_sip_3_100mil obsolete svg /Applications/Fritzing.app/Contents/Resources/fritzing-parts/svg/obsolete/icon/mystery_part_icon.svg
module DIP-Relay-D31A:71d4db74a3a0ec43d9303ddffee7361b obsolete svg /Applications/Fritzing.app/Contents/Resources/fritzing-parts/svg/obsolete/icon/DIP_Relay_D31A_icon.svg
module Generic female header - 2 pins:generic_female_pin_header_2_100mil obsolete svg /Applications/Fritzing.app/Contents/Resources/fritzing-parts/svg/obsolete/icon/generic_female_header.svg
module Audio Jack (TRS) 3.5mm:stereo-jack-3_5mm obsolete svg /Applications/Fritzing.app/Contents/Resources/fritzing-parts/svg/obsolete/icon/stereo-jack-3_5mm.svg
Setting platform to Arduino
updating link
Setting board to Arduino BT
Setting board to Arduino UNO
Setting board to Arduino UNO
Setting board to Arduino UNO
Setting port to cu.Bluetooth-Incoming-Port
adding layer kin 57681 3 25 7f80caa216e0
adding layer kin 57682 3 18 7f80caa20ca0
TLS on Want: Secure Transport, macOS 10.15 Found: Secure Transport, macOS 10.15
finish up sketch loading
https://fritzing.org/download/feed/atom/mac-os-x-105/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
http check new version
handle error
handle error done
http check new version no error
remote https://github.com/fritzing/fritzing-parts.git
current head refs/heads/release_0.9.6
head oid b82c8c3abd9bca5d30a4d0c28fb4327ac38cf511
remote head name HEAD, 0, refs/heads/develop
ref oid ed32113a7741f1389f1e44a5316e94ac4191c816
remote head name refs/heads/206, 0, 
ref oid 63ea29837ec3fdabff09665e21e90e11d77cc957
remote head name refs/heads/Nitaym-frc-parts, 0, 
ref oid c149d2b6b334b8b8add664dda59bdf869693232f
remote head name refs/heads/arduino-logo, 0, 
ref oid 98589d39054dda482d01ed504dd14d79d4357e86
remote head name refs/heads/arduino_due_icsp, 0, 
ref oid 768e126b197dc91c002e768ab6aeacd017707dc5
remote head name refs/heads/ci, 0, 
ref oid 1e073999efc0dc7c47396604941d68bfa68974a6
remote head name refs/heads/develop, 0, 
ref oid ed32113a7741f1389f1e44a5316e94ac4191c816
remote head name refs/heads/generic-smd, 0, 
ref oid 186b9479498e5124caecaf409763c80c8788adc6
remote head name refs/heads/gh-pages, 0, 
ref oid 981c95df0708d5dcca8be9cf52cb08f09c5f2fb4
remote head name refs/heads/main, 0, 
ref oid 640fa25650211afccd369f960375ade8ec3e8653
remote head name refs/heads/master, 0, 
ref oid e79a69765026f3fda8aab1b3e7a4952c28047a62
remote head name refs/heads/obsolete, 0, 
ref oid 7cd715cba903e148c3394b16d1316416e481034d
remote head name refs/heads/release_0.9.6, 0, 
ref oid b82c8c3abd9bca5d30a4d0c28fb4327ac38cf511
loading bin 'My Parts'

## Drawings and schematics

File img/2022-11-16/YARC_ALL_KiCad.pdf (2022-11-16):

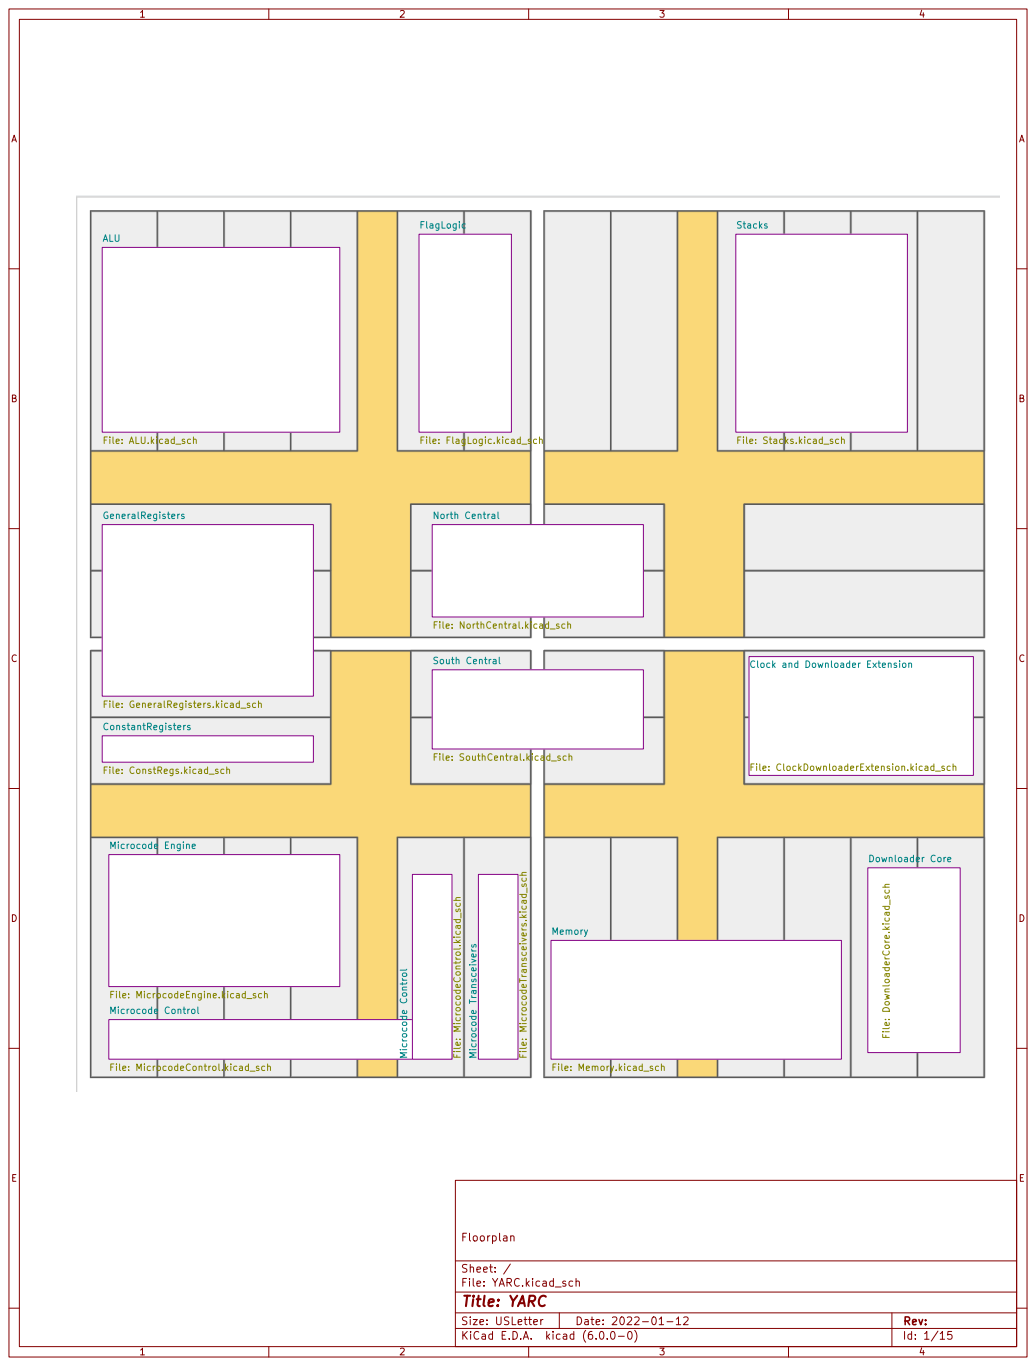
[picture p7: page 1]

File: ALU.kicad_sch
File: GeneralRegisters.kicad_sch Microcode Control File: MicrocodeControl.kicad_sch Microcode Engine

File: YARC.kicad_sch Sheet: / Floorplan

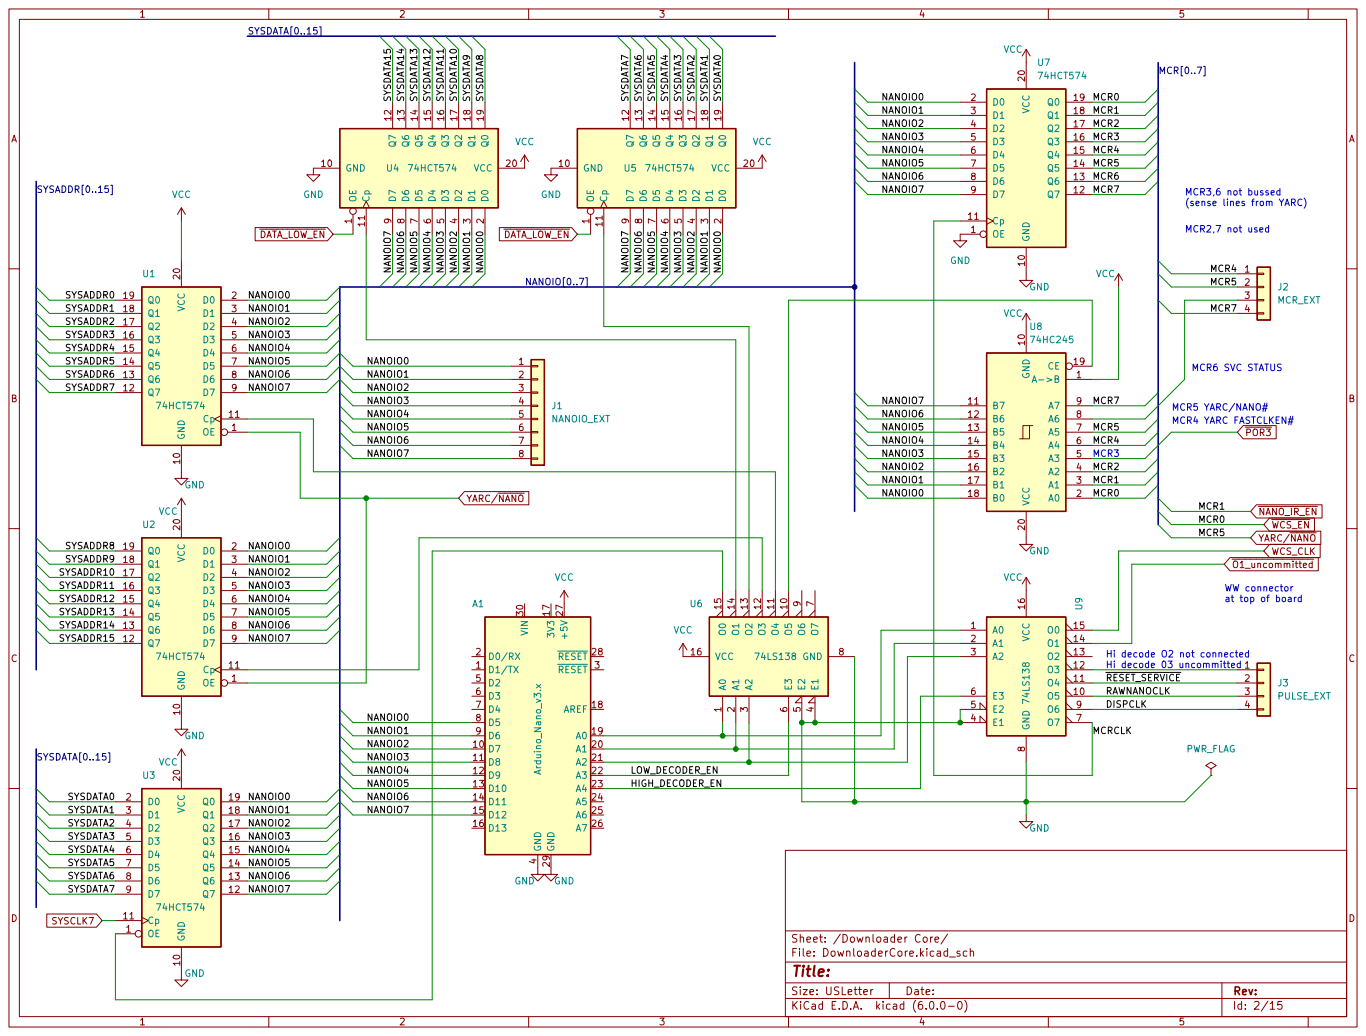
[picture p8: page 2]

(sense lines from YARC) WW connector at top of board Hi decode O2 not connected Hi decode 03 uncommitted MCR4 YARC FASTCLKEN# MCR6 SVC STATUS MCR3

File: DownloaderCore.kicad_sch Sheet: /Downloader Core/

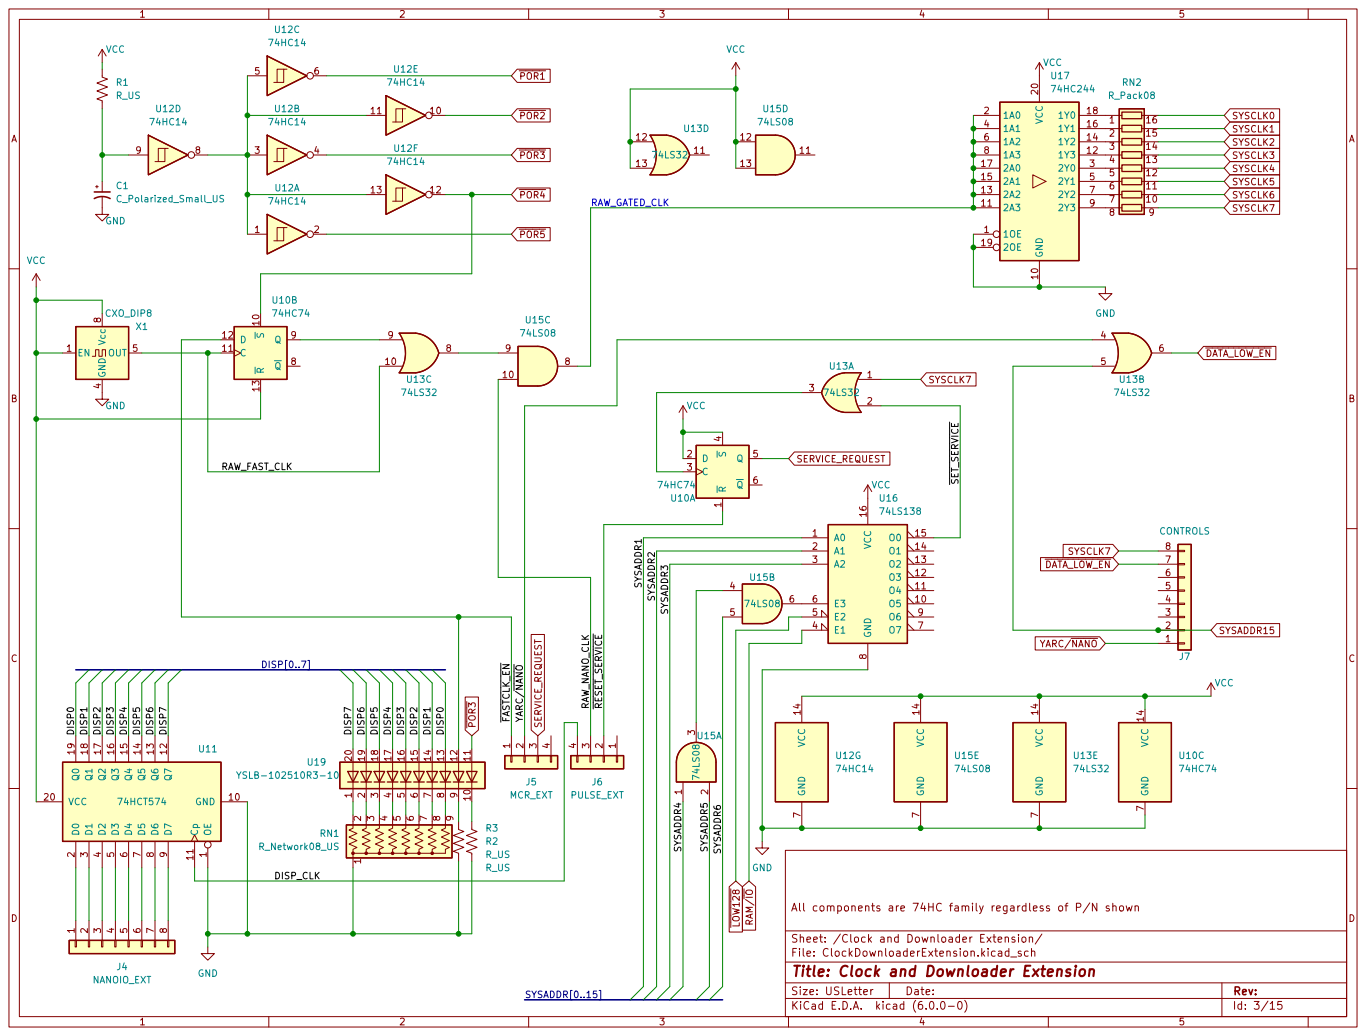
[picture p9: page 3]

File: ClockDownloaderExtension.kicad_sch Sheet: /Clock and Downloader Extension/ All components are 74HC family regardless of P/N shown ~{R} 1 D

Id: 3/15 Title: Clock and Downloader Extension

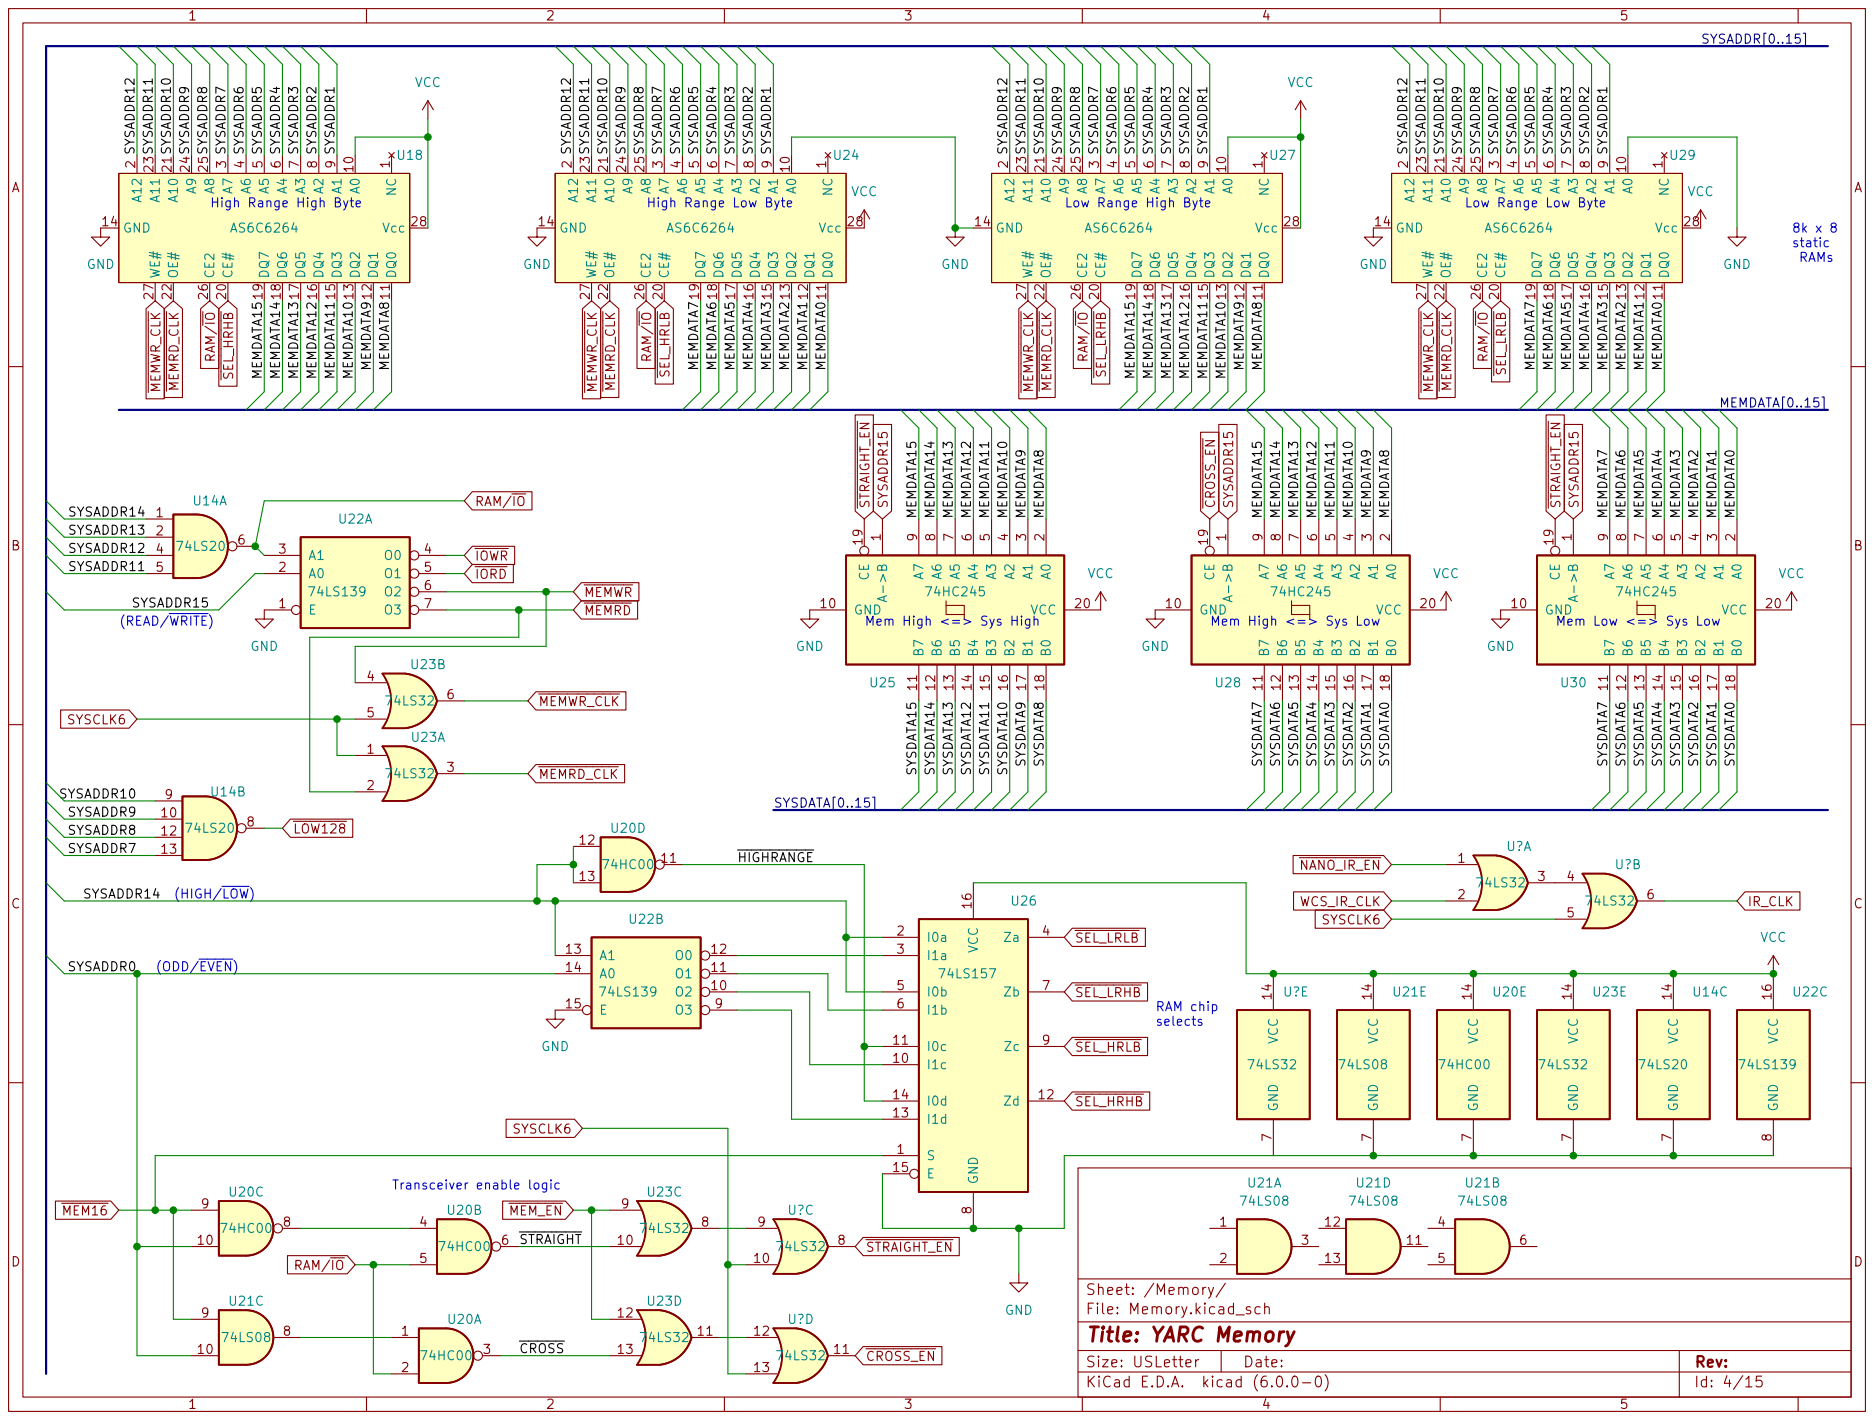
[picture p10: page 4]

9U18 AS6C6264 VCC GND VCC 14 GND

2 CE# 20 A10 21 OE# 22 A11 23 A9 24 A8 25 CE2 26 WE# 27 Vcc 28 A7

High Range High Byte

High Range Low Byte

Sheet: /Memory/
File: Memory.kicad_sch
Id: 4/15 Title: YARC Memory

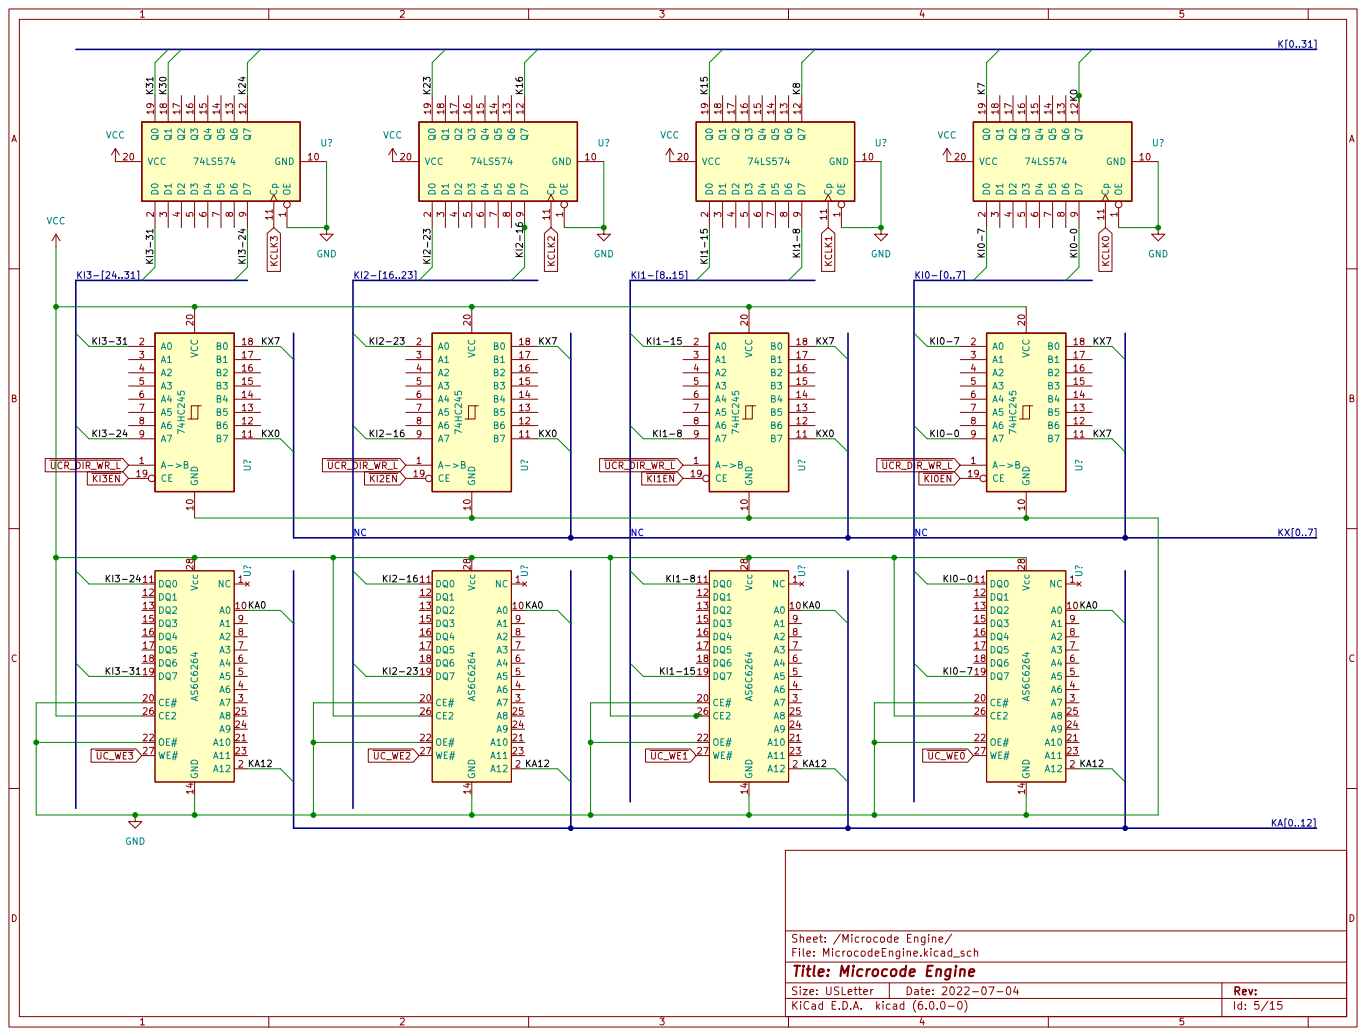
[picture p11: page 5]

Sheet: /Microcode Engine/
File: MicrocodeEngine.kicad_sch
Id: 5/15 Title: Microcode Engine

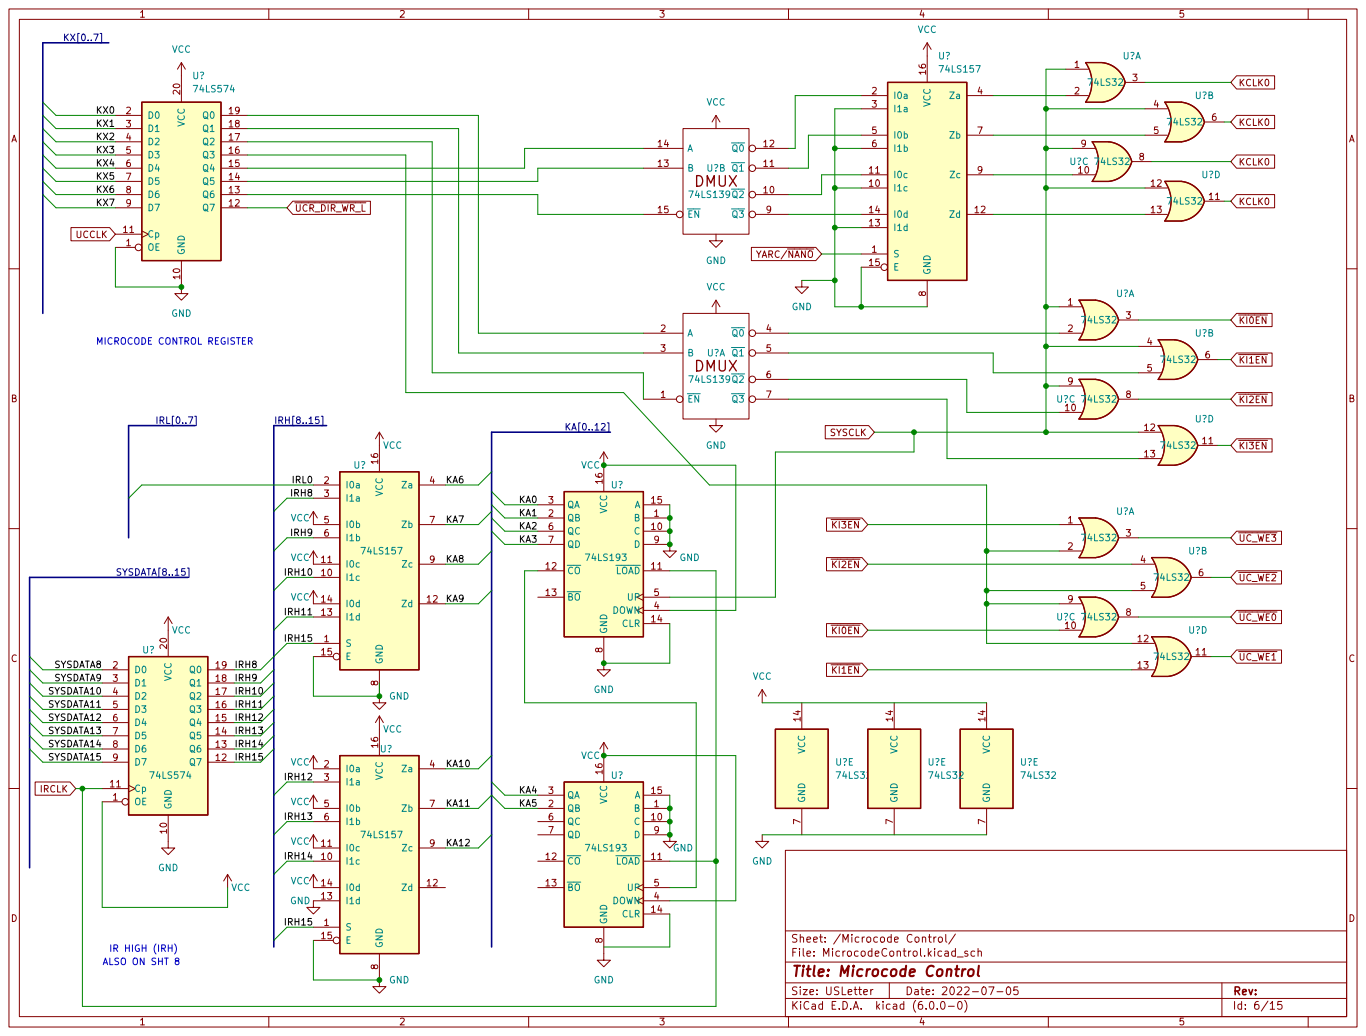
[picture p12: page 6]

Id: 6/15 Title: Microcode Control

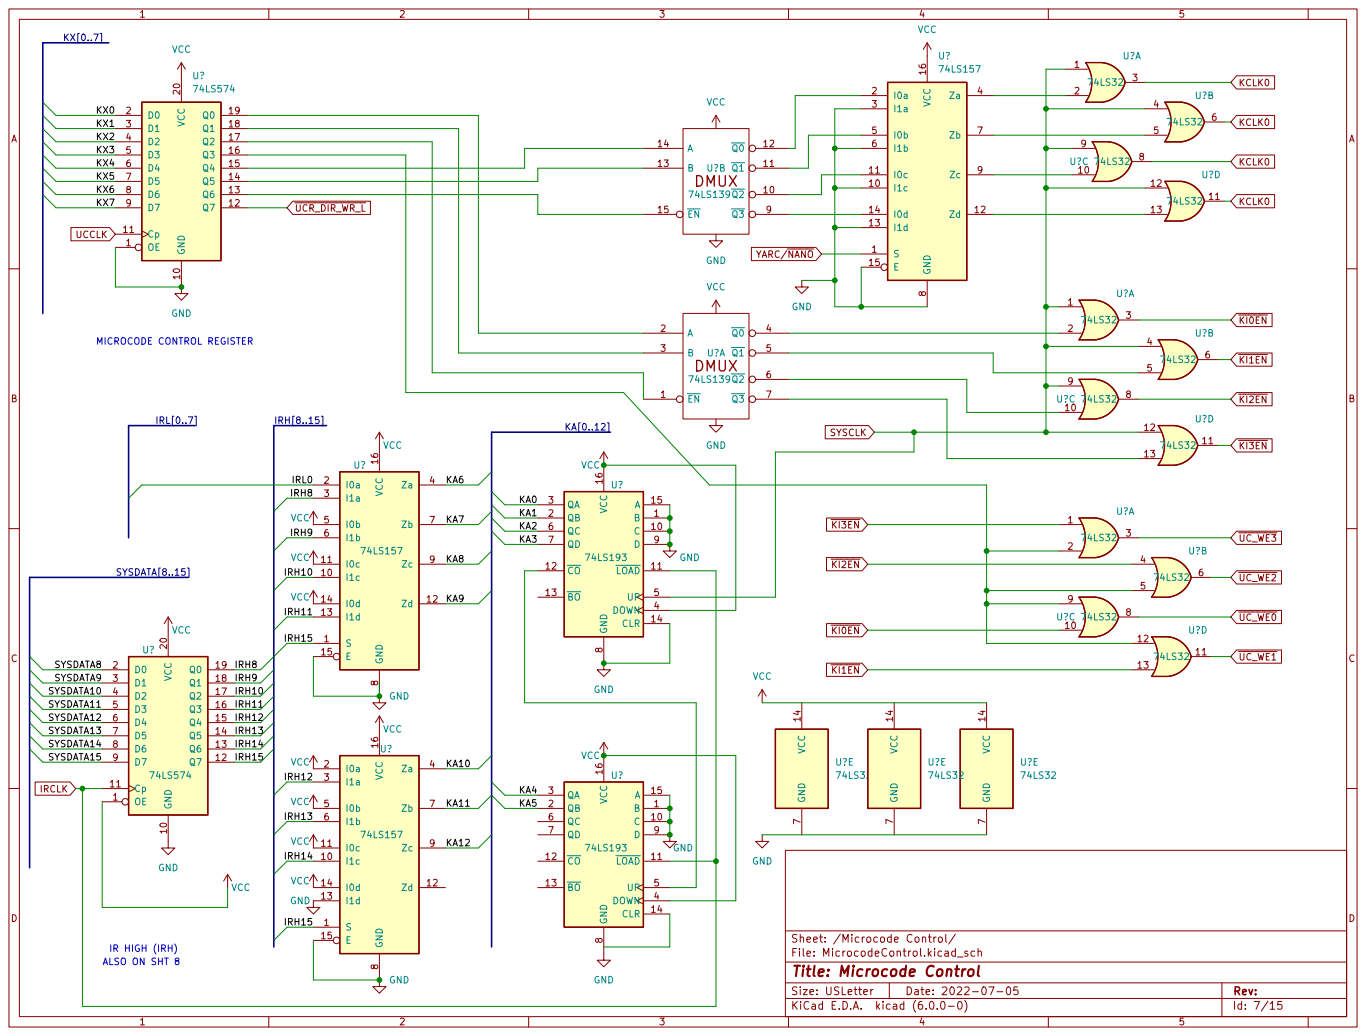
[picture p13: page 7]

Id: 7/15 Title: Microcode Control

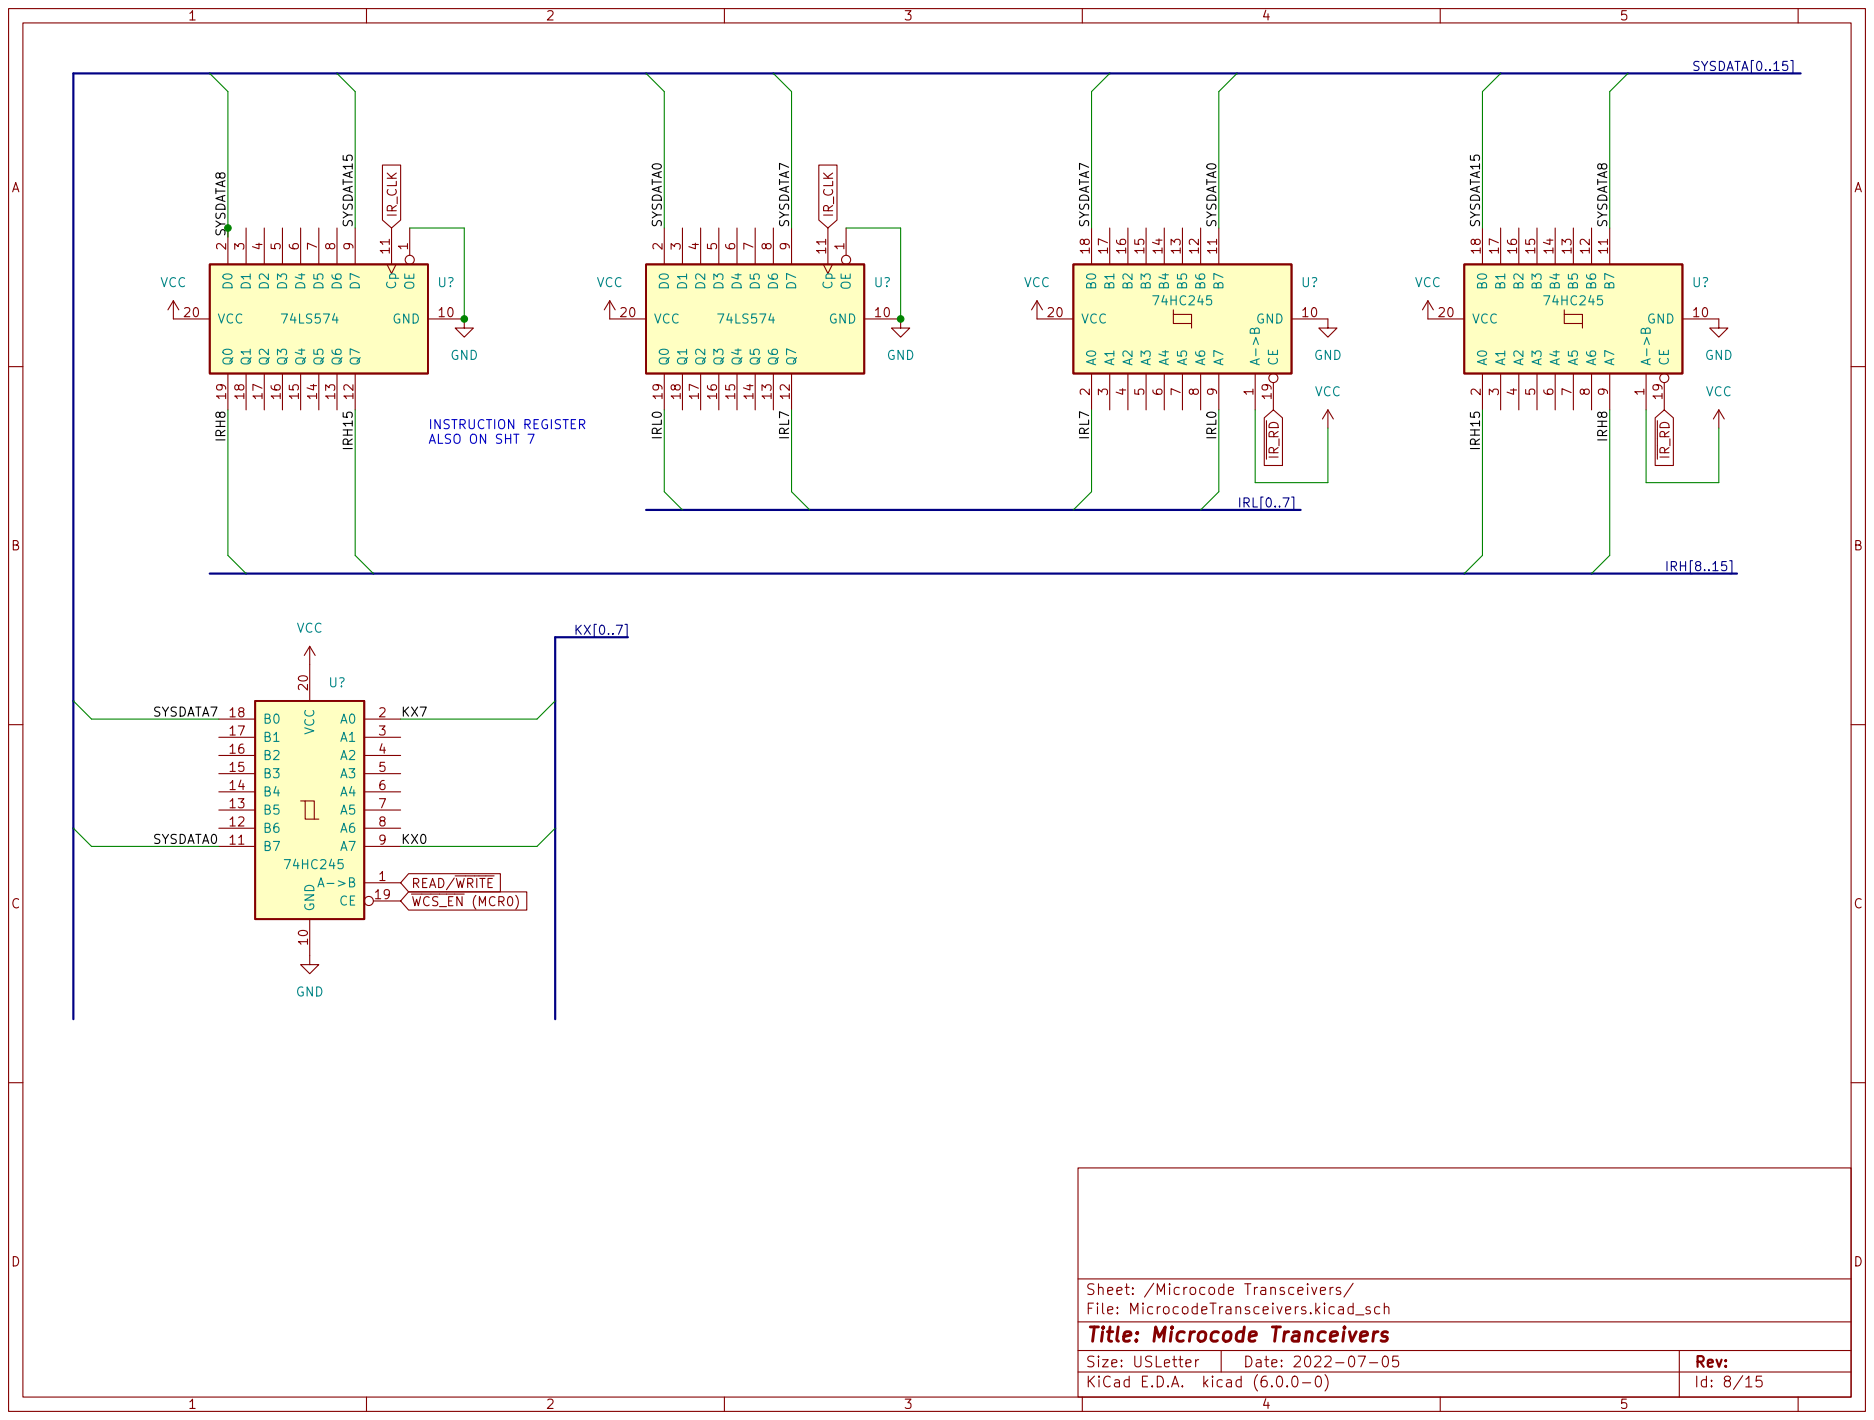
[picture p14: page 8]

File: MicrocodeTransceivers.kicad_sch Sheet: /Microcode Transceivers/ A->B

Id: 8/15 Title: Microcode Tranceivers

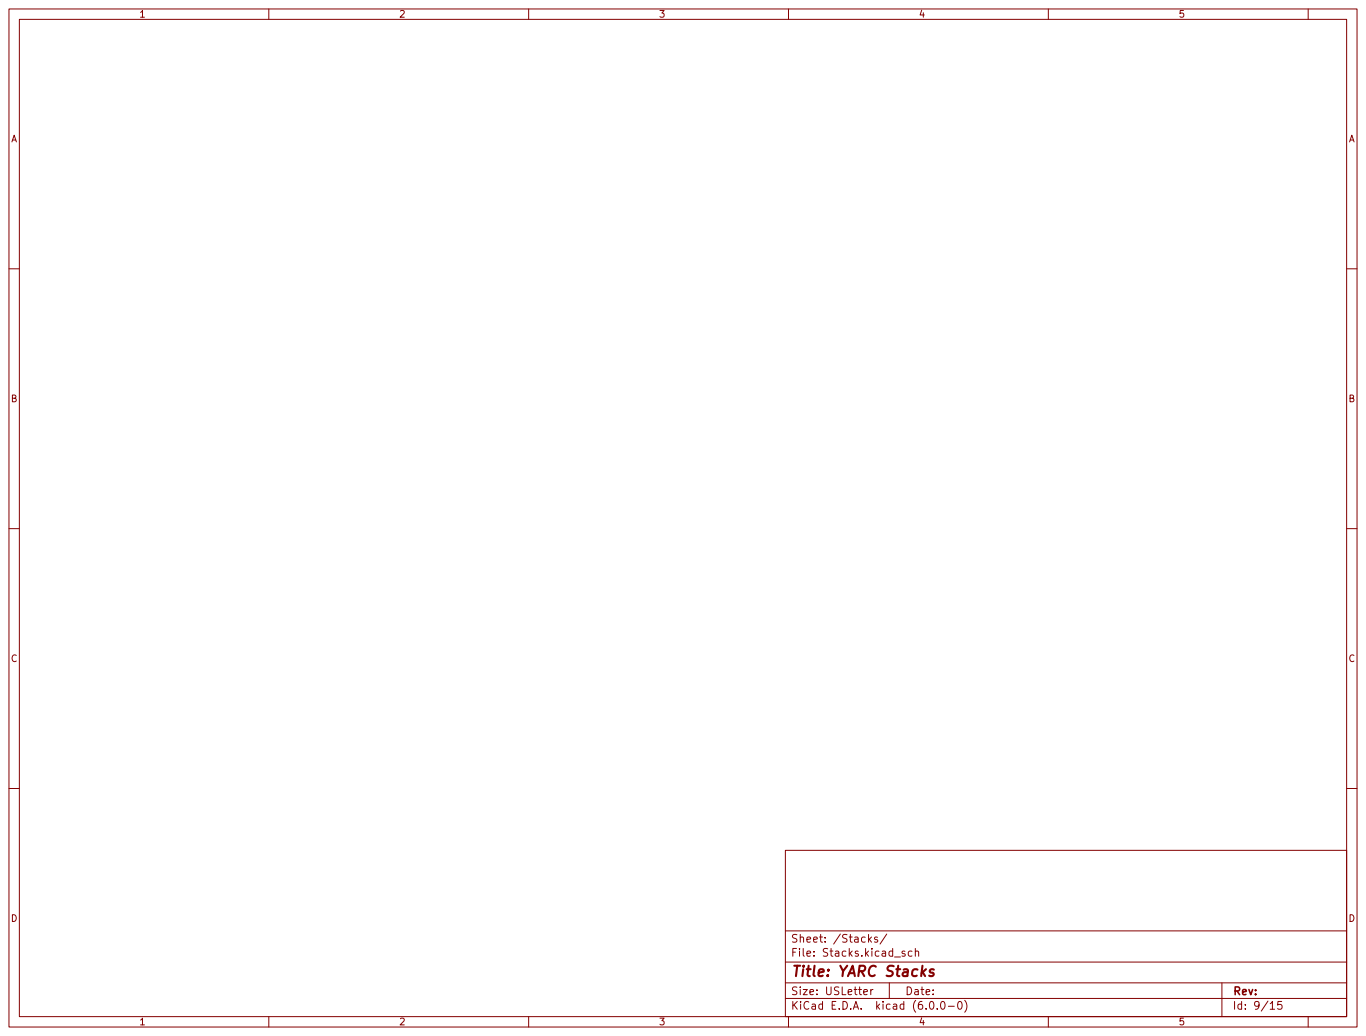
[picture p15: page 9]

File: Stacks.kicad_sch Sheet: /Stacks/
Id: 9/15 Title: YARC Stacks

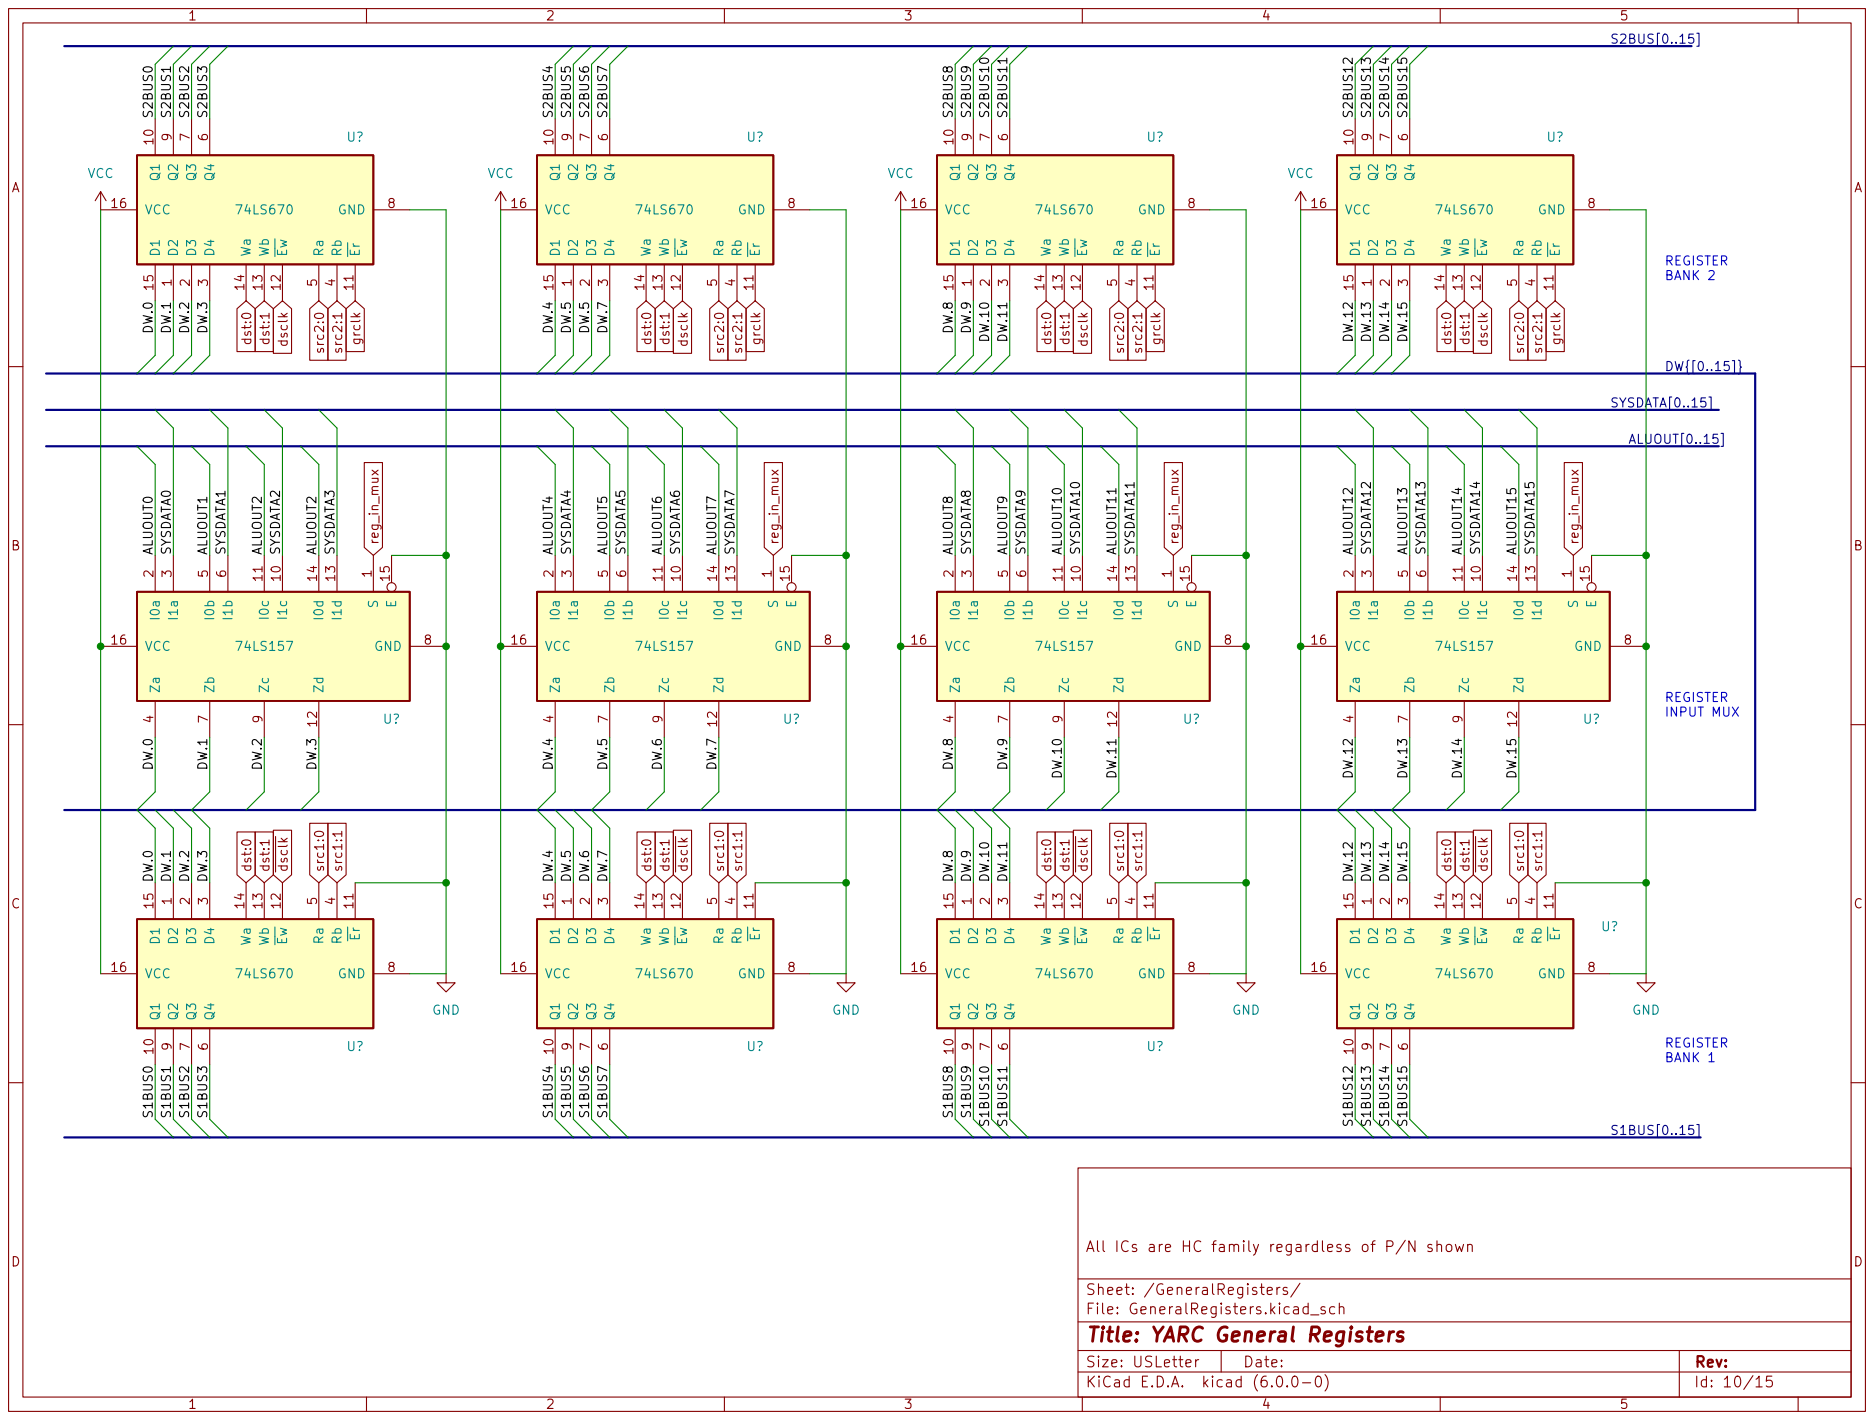
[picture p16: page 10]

1 Q1 10 ~{Er} 11 ~{Ew} 12 Wb 13 Wa 14 D1 15 VCC 16 D3

All ICs are HC family regardless of P/N shown
Sheet: /GeneralRegisters/
File: GeneralRegisters.kicad_sch
Id: 10/15 Title: YARC General Registers

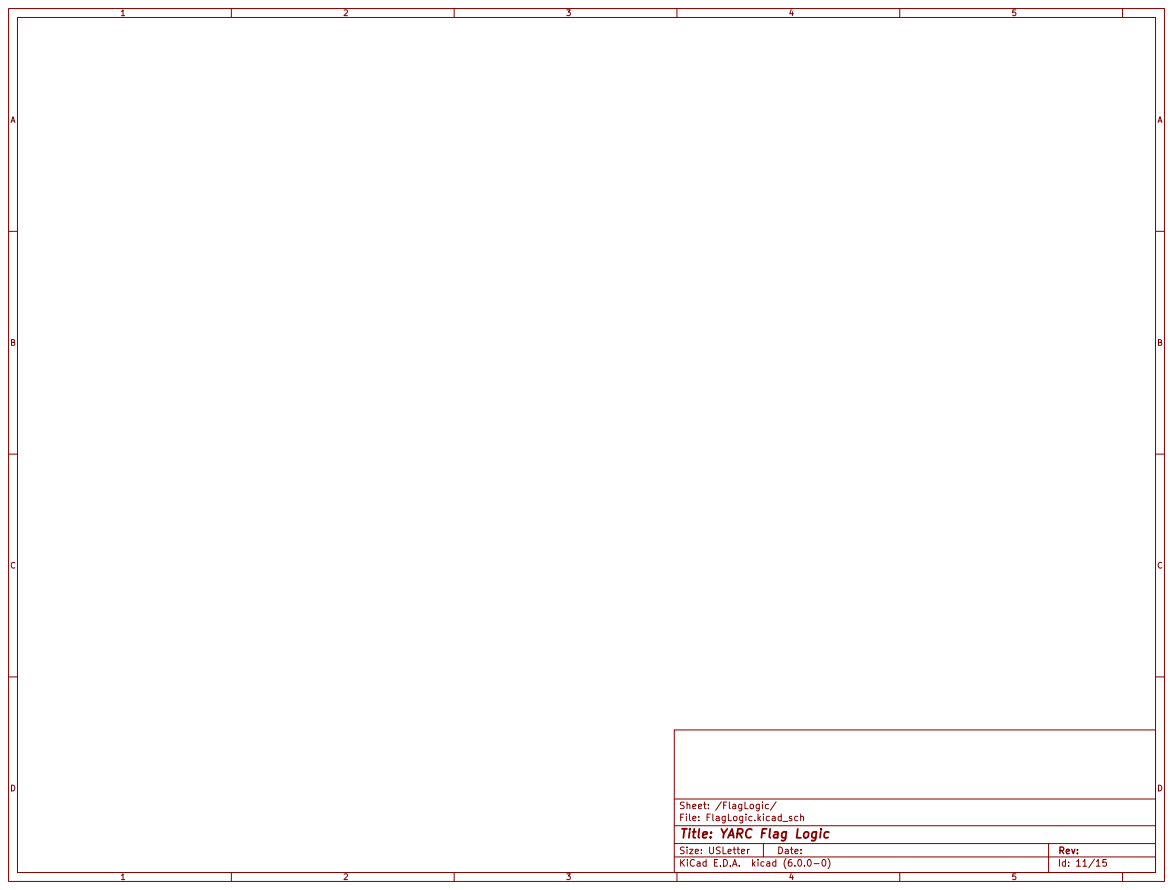
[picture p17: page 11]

Sheet: /FlagLogic/
File: FlagLogic.kicad_sch
Id: 11/15 Title: YARC Flag Logic

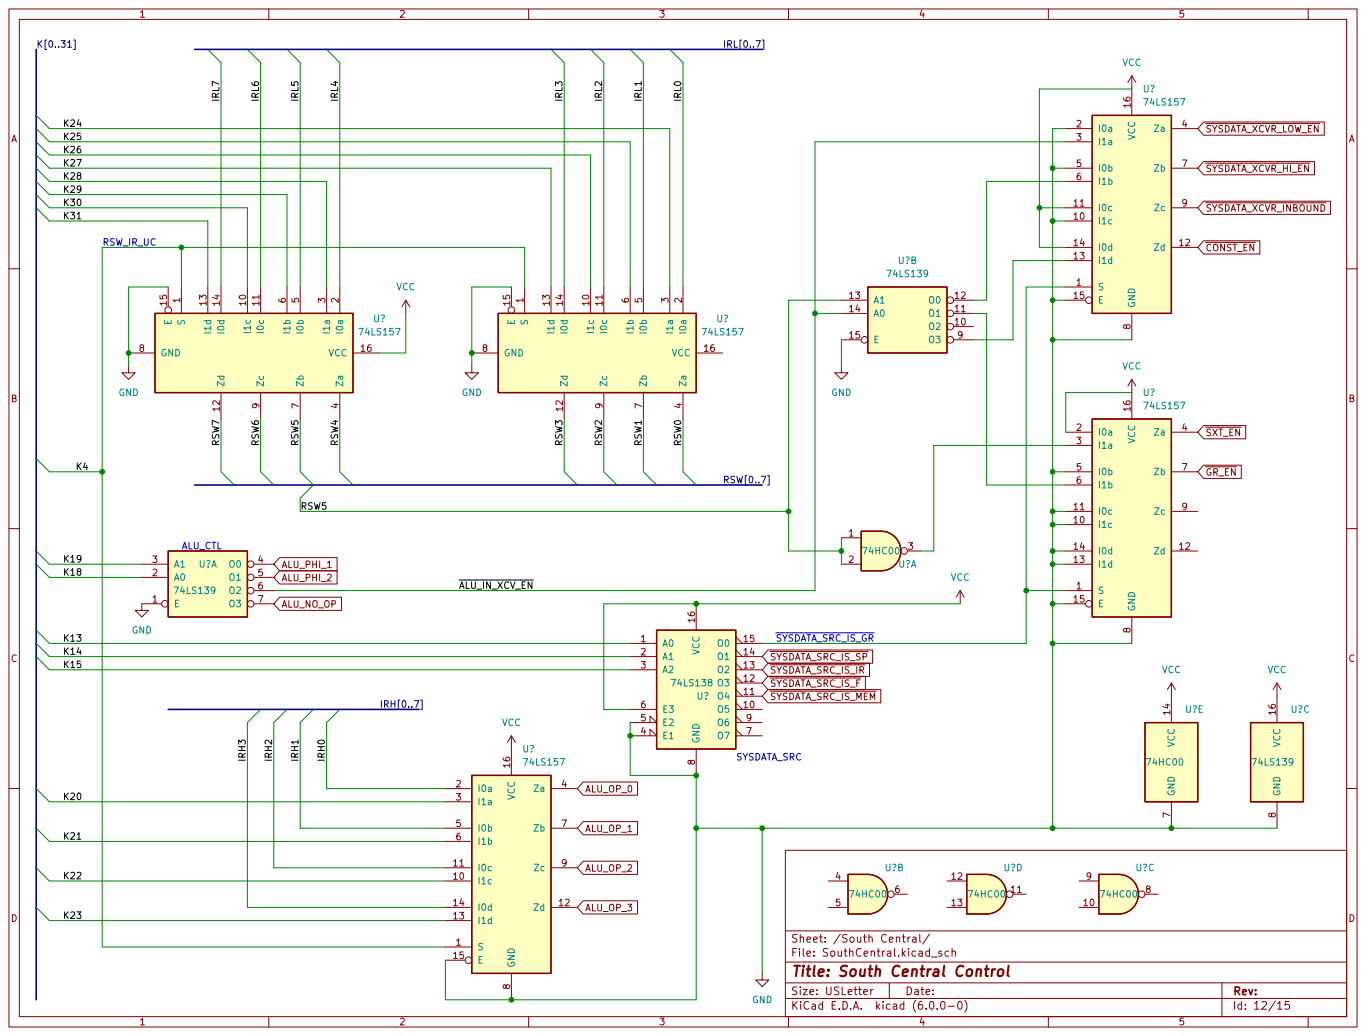
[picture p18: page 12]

Id: 12/15 Title: South Central Control


File: NorthCentral.kicad_sch Sheet: /North Central/ All ICs are HC family regardless of P/N shown

Id: 14/15 Title: North Central distribution logic


File: ALU.kicad_sch Sheet: /ALU/ All ICs are HC family regardless of P/N shown

Id: 15/15 Title: YARC ALU


All parts are 74HC family regardless of P/N shown
Sheet: /ConstantRegisters/
File: ConstRegs.kicad_sch
Id: 15/15 Title: Constant Registers

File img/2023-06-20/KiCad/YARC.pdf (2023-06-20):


ALUControls File: ALUControls.kicad_sch ConstantRegisters

Stacks File: Stacks.kicad_sch GeneralRegisters

File: YARC.kicad_sch Sheet: / Floorplan


Hi decode O2 not connected

File: DownloaderCore.kicad_sch Sheet: /Downloader Core/ GND


Id: 3/17 Title: Clock and Downloader Extension


2 CE# 20 A10 21 OE# 22 A11 23 A9 24 A8 25 CE2 26 WE# 27 Vcc 28 A7

High Range Low Byte

Low Range High Byte

RAMs Low Range Low Byte

Mem High <=> Sys High

Mem High <=> Sys Low

Mem Low <=> Sys Low

regardless of the part number shown. 74LS08 "D" unit is also uncommitted.

Transceiver enable logic. RAM/~{IO}
from above. ~{MEM16} from microcode.
~{MEMIO_EN} from U88 in Central.

It was accidentally deleted here.

File: Memory.kicad_sch
Id: 4/17 Title: YARC Memory


File: MicrocodeEngine.kicad_sch
Id: 5/17 Title: Microcode Engine


Id: 6/17 Title: Microcode Control


Id: 7/17 Title: Microcode Control


File: MicrocodeTransceivers.kicad_sch Sheet: /Microcode Transceivers/
Id: 8/17 Title: Microcode Tranceivers


File: Stacks.kicad_sch Sheet: /Stacks/
Id: 9/17 Title: YARC Stacks


1 Q1 10 ~{Er} 11 ~{Ew} 12 Wb 13 Wa 14 D1 15 VCC 16 D3

All ICs are HC family regardless of P/N shown D2

Sheet: /GeneralRegisters/
File: GeneralRegisters.kicad_sch
Id: 10/17 Title: YARC General Registers


LOCATED IN FLAGS U107C and U107D

ALU INPUT AND OUTPUT CONTROLS

File: FlagLogic.kicad_sch
Id: 11/17 Title: YARC Flag Logic


THIS SHEET IS ACTUALLY "WEST" CENTRAL
74LS157 VCC
~{GR_EN} SYSDATA_XCVR_INBOUND

Note: inputs on pins 5 and 6 were reversed
relative to the CircuitSim simulation because
it was convenient to wire the A and B inputs
to the sysdata transceivers the other way in
the register block.

~{MEMIO_WR} is K7. MEMIO_RD and ~{MEMIO_EN}
to memory subsystem (YARC Memory, sheet 4)

Id: 12/17 Title: South Central Control


SYSADDR[0..15]
rest of components are in the Flags. Enable for control decoder A0 to control decoder A1 to control decoder RAM Carry in (A8) when NANO#

~{FQTR_NOT_C_IN}

~{FQTR_C_IN} | I1c 10

All output signals on
this side are found

on the ALU schematic. This mux physically

This control is essentially YARC/NANO#. When YARC has

control, it is always low.

ALU RAM WRITE DELAY LINE

File: NorthCentral.kicad_sch Sheet: /North Central/ All ICs are HC family regardless of P/N shown GND

Id: 14/17 Title: North Central distribution logic

ALU CONTROL REGISTER (ACR)


Id: 15/17 Title: YARC ALU


All parts are 74HC family regardless of P/N shown 1

Sheet: /ConstantRegisters/
File: ConstRegs.kicad_sch
Id: 15/17 Title: Constant Registers


We cannot distinguish sheets 6, 7, or 8 because of
bugs in KiCad (microcode control has two identities)
6-PIN FROM MCR MCR bit 0x80 (bit 7)

YARC/~{NANO} to ALU Control DOES NOT EXIST

~{ADDRESS_XCVR_EN} DOES NOT EXIST WCS_CLK sheet 6/7/8 WCS_EN sheet 6/7/8 ACR_CLK sheet 14 (North Central) NOT USED

A second 7-pin physical connector
is located adjacent to the 6-pin
that brings signals from the Nano.

U100C and U100D are in the memory schematic near the bottom - Row D, Column 3. NORTH END

This is another delay to prevent the write signal
from reaching the register array until after the
data has settled in the second half of clock. It's

similar to the inverter chain in North Central. The effect of the "D" unit is merely to invert YARC/NANO#

But it allows for future expansion (in case something else
ever needs to drive the address bus when YARC).

This sheet summarizes the use of the YARC kludge space,
which is located north of the main system memory. Some
logic from the kludge space appears on other sheets.

File: KludgeSpace.kicad_sch
Id: 16/17 Title: YARC Kludge Space


FLAGS INPUT MUX NW CORNER OF GRs
15 VCC 16
SYSDATA0 SYSDATA1 FMUXIN_Z

CARRY-SELECT CONTROLSCARRY AND ZERO FLAG LOGIC

LOCATED IN ALU CORE

U93D is located in general register controls. CARRY-IN LOGIC

IN THE GENERAL REGISTERS AREA. REGISTERED FLAGS NW CORNER OF ALU

File: ALUControls.kicad_sch Sheet: /ALUControls/ All ICs are HC series regardless of P/N shown VCC 14 GND

Id: 17/17 Title: YARC ALU Controls

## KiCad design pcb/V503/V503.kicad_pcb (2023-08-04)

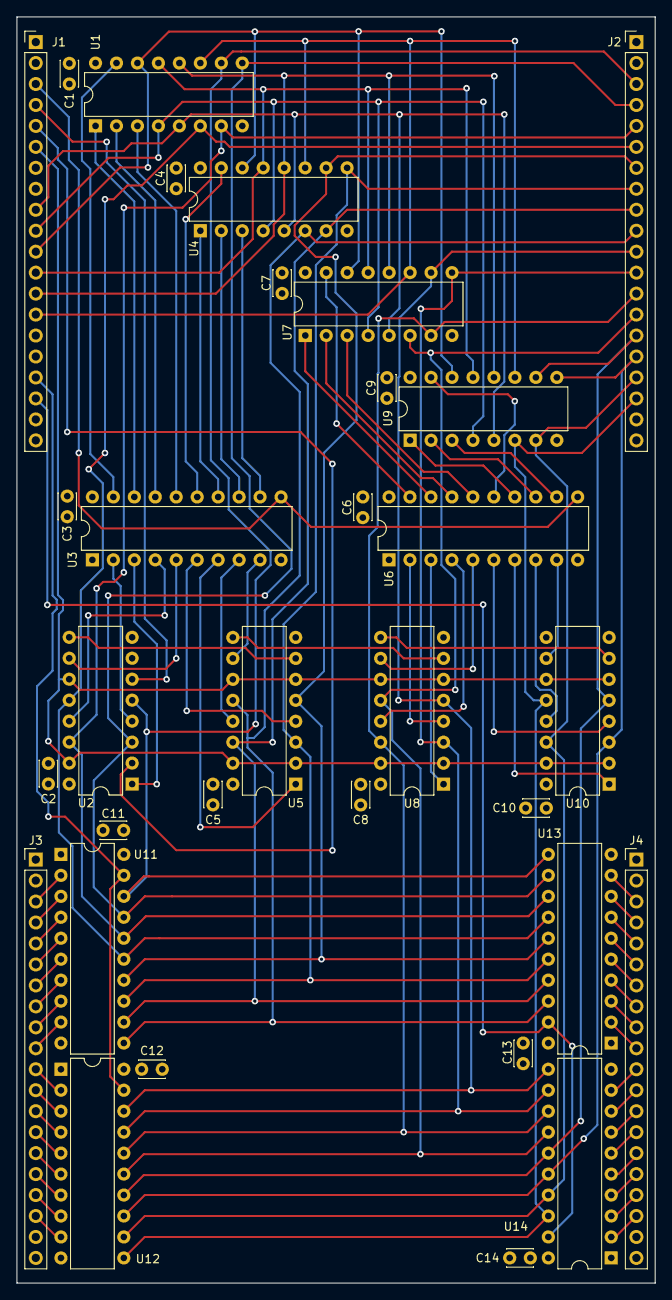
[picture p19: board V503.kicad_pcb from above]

Board: 4 copper layers, 77.3 x 153.4 mm, 32 parts (0 on the bottom side), 97 nets.

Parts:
C1, C2, C3, C4, C5, C6, C7, C8, C9, C10, C11, C12, C13, C14: C_Small; C_Disc_D3.0mm_W2.0mm_P2.50mm
J1, J2, J3, J4: Conn_01x20_Pin; PinHeader_1x20_P2.54mm_Vertical
U1, U4, U7, U9: 74LS670; DIP-16_W7.62mm
U2, U5, U8, U10: 74LS283; DIP-16_W7.62mm
U3, U6: 74LS574; DIP-20_W7.62mm
U11, U12, U13, U14: 74LS245; DIP-20_W7.62mm

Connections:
ALU0: J3.3, U11.2 (A0)
ALU1: J3.4, U11.3 (A1)
ALU2: J3.5, U11.4 (A2)
ALU3: J3.6, U11.5 (A3)
ALU4: J3.7, U11.6 (A4)
ALU5: J3.8, U11.7 (A5)
ALU6: J3.9, U11.8 (A6)
ALU7: J3.10, U11.9 (A7)
ALU8: J3.11, U12.2 (A0)
ALU9: J3.12, U12.3 (A1)
ALU10: J3.13, U12.4 (A2)
ALU11: J3.14, U12.5 (A3)
ALU12: J3.15, U12.6 (A4)
ALU13: J3.16, U12.7 (A5)
ALU14: J3.17, U12.8 (A6)
ALU15: J3.18, U12.9 (A7)
CO4: U2.9 (C4), U5.7 (C0)
CO8: U5.9 (C4), U8.7 (C0)
CO12: U8.9 (C4), U10.7 (C0)
GND: C1.2, C2.2, C3.2, C4.2, C5.2, C6.2, C7.2, C8.2, C9.2, C10.2, C11.2, C12.2, C13.2, C14.2, J2.1, J2.2, J2.19, J2.20, J4.1, J4.2, J4.19, J4.20, U1.8 (GND), U2.7 (C0), U2.8 (GND), U3.1 (OE), U3.10 (GND), U4.8 (GND), U5.8 (GND), U6.1 (OE), U6.10 (GND), U7.8 (GND), U8.8 (GND), U9.8 (GND), U10.8 (GND), U11.10 (GND), U12.10 (GND), U13.1 (A->B), U13.10 (GND), U14.1 (A->B), U14.10 (GND)
HLD0: U1.15 (D1), U3.19 (Q0)
HLD1: U1.1 (D2), U3.18 (Q1)
HLD2: U1.2 (D3), U3.17 (Q2)
HLD3: U1.3 (D4), U3.16 (Q3)
HLD4: U3.15 (Q4), U4.15 (D1)
HLD5: U3.14 (Q5), U4.1 (D2)
HLD6: U3.13 (Q6), U4.2 (D3)
HLD7: U3.12 (Q7), U4.3 (D4)
HLD8: U6.19 (Q0), U7.15 (D1)
HLD9: U6.18 (Q1), U7.1 (D2)
HLD10: U6.17 (Q2), U7.2 (D3)
HLD11: U6.16 (Q3), U7.3 (D4)
HLD12: U6.15 (Q4), U9.15 (D1)
HLD13: U6.14 (Q5), U9.1 (D2)
HLD14: U6.13 (Q6), U9.2 (D3)
HLD15: U6.12 (Q7), U9.3 (D4)
Ra: J1.9, U1.5 (Ra), U4.5 (Ra), U7.5 (Ra), U9.5 (Ra)
Rb: J1.10, U1.4 (Rb), U4.4 (Rb), U7.4 (Rb), U9.4 (Rb)
SRC2:0: J1.4, U2.6 (B1)
SRC2:1: J1.5, U2.2 (B2)
SRC2:2: J1.6, U2.11 (B4), U2.15 (B3), U5.2 (B2), U5.6 (B1), U5.11 (B4), U5.15 (B3), U8.2 (B2), U8.6 (B1), U8.11 (B4), U8.15 (B3), U10.2 (B2), U10.6 (B1), U10.11 (B4), U10.15 (B3)
SUM0: U2.4 (S1), U3.2 (D0)
SUM1: U2.1 (S2), U3.3 (D1)
SUM2: U2.13 (S3), U3.4 (D2)
SUM3: U2.10 (S4), U3.5 (D3)
SUM4: U3.6 (D4), U5.4 (S1)
SUM5: U3.7 (D5), U5.1 (S2)
SUM6: U3.8 (D6), U5.13 (S3)
SUM7: U3.9 (D7), U5.10 (S4)
SUM8: U6.2 (D0), U8.4 (S1)
SUM9: U6.3 (D1), U8.1 (S2)
SUM10: U6.4 (D2), U8.13 (S3)
SUM11: U6.5 (D3), U8.10 (S4)
SUM12: U6.6 (D4), U10.4 (S1)
SUM13: U6.7 (D5), U10.1 (S2)
SUM14: U6.8 (D6), U10.13 (S3)
SUM15: U6.9 (D7), U10.10 (S4)
SYSADDR0: J2.3, U1.10 (Q1), U2.5 (A1), U11.18 (B0), U13.11 (B7)
SYSADDR1: J2.4, U1.9 (Q2), U2.3 (A2), U11.17 (B1), U13.12 (B6)
SYSADDR2: J2.5, U1.7 (Q3), U2.14 (A3), U11.16 (B2), U13.13 (B5)
SYSADDR3: J2.6, U1.6 (Q4), U2.12 (A4), U11.15 (B3), U13.14 (B4)
SYSADDR4: J2.7, U4.10 (Q1), U5.5 (A1), U11.14 (B4), U13.15 (B3)
SYSADDR5: J2.8, U4.9 (Q2), U5.3 (A2), U11.13 (B5), U13.16 (B2)
SYSADDR6: J2.9, U4.7 (Q3), U5.14 (A3), U11.12 (B6), U13.17 (B1)
SYSADDR7: J2.10, U4.6 (Q4), U5.12 (A4), U11.11 (B7), U13.18 (B0)
SYSADDR8: J2.11, U7.10 (Q1), U8.5 (A1), U12.18 (B0), U14.11 (B7)
SYSADDR9: J2.12, U7.9 (Q2), U8.3 (A2), U12.17 (B1), U14.12 (B6)
SYSADDR10: J2.13, U7.7 (Q3), U8.14 (A3), U12.16 (B2), U14.13 (B5)
SYSADDR11: J2.14, U7.6 (Q4), U8.12 (A4), U12.15 (B3), U14.14 (B4)
SYSADDR12: J2.15, U9.10 (Q1), U10.5 (A1), U12.14 (B4), U14.15 (B3)
SYSADDR13: J2.16, U9.9 (Q2), U10.3 (A2), U12.13 (B5), U14.16 (B2)
SYSADDR14: J2.17, U9.7 (Q3), U10.14 (A3), U12.12 (B6), U14.17 (B1)
SYSADDR15: J2.18, U9.6 (Q4), U10.12 (A4), U12.11 (B7), U14.18 (B0)
SYSCLK: J1.3, U3.11 (Cp), U6.11 (Cp)
SYSDATA0: J4.3, U13.9 (A7)
SYSDATA1: J4.4, U13.8 (A6)
SYSDATA2: J4.5, U13.7 (A5)
SYSDATA3: J4.6, U13.6 (A4)
SYSDATA4: J4.7, U13.5 (A3)
SYSDATA5: J4.8, U13.4 (A2)
SYSDATA6: J4.9, U13.3 (A1)
SYSDATA7: J4.10, U13.2 (A0)
SYSDATA8: J4.11, U14.9 (A7)
SYSDATA9: J4.12, U14.8 (A6)
SYSDATA10: J4.13, U14.7 (A5)
SYSDATA11: J4.14, U14.6 (A4)
SYSDATA12: J4.15, U14.5 (A3)
SYSDATA13: J4.16, U14.4 (A2)
SYSDATA14: J4.17, U14.3 (A1)
SYSDATA15: J4.18, U14.2 (A0)
VCC: C1.1, C2.1, C3.1, C4.1, C5.1, C6.1, C7.1, C8.1, C9.1, C10.1, C11.1, C12.1, C13.1, C14.1, J1.1, J1.2, J1.7, J1.8, J1.15, J1.16, J1.19, J1.20, J3.1, J3.2, J3.19, J3.20, U1.16 (VCC), U2.16 (VCC), U3.20 (VCC), U4.16 (VCC), U5.16 (VCC), U6.20 (VCC), U7.16 (VCC), U8.16 (VCC), U9.16 (VCC), U10.16 (VCC), U11.1 (A->B), U11.20 (VCC), U12.1 (A->B), U12.20 (VCC), U13.20 (VCC), U14.20 (VCC)
Wa: J1.11, U1.14 (Wa), U4.14 (Wa), U7.14 (Wa), U9.14 (Wa)
Wb: J1.12, U1.13 (Wb), U4.13 (Wb), U7.13 (Wb), U9.13 (Wb)
~ALUtoA: J1.17, U11.19 (CE), U12.19 (CE)
~AtoD: J1.18, U13.19 (CE), U14.19 (CE)
~Er: J1.14, U1.11 (~Er), U4.11 (~Er), U7.11 (~Er), U9.11 (~Er)
~Ew: J1.13, U1.12 (~Ew), U4.12 (~Ew), U7.12 (~Ew), U9.12 (~Ew)

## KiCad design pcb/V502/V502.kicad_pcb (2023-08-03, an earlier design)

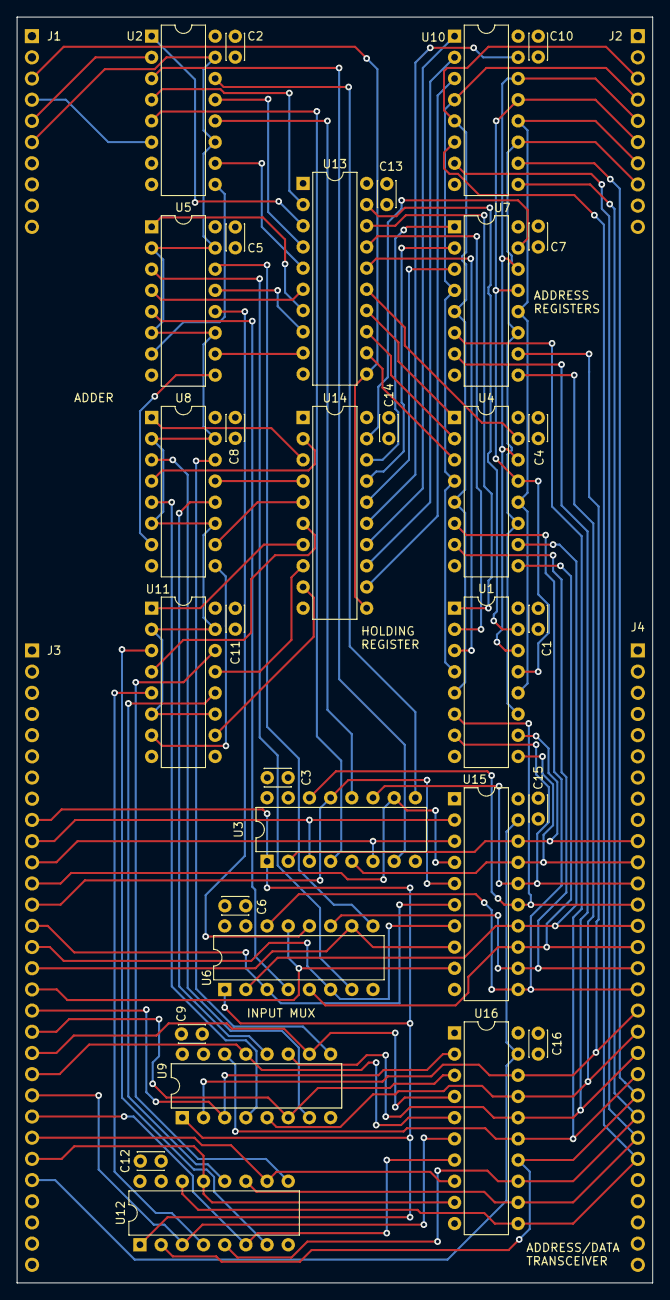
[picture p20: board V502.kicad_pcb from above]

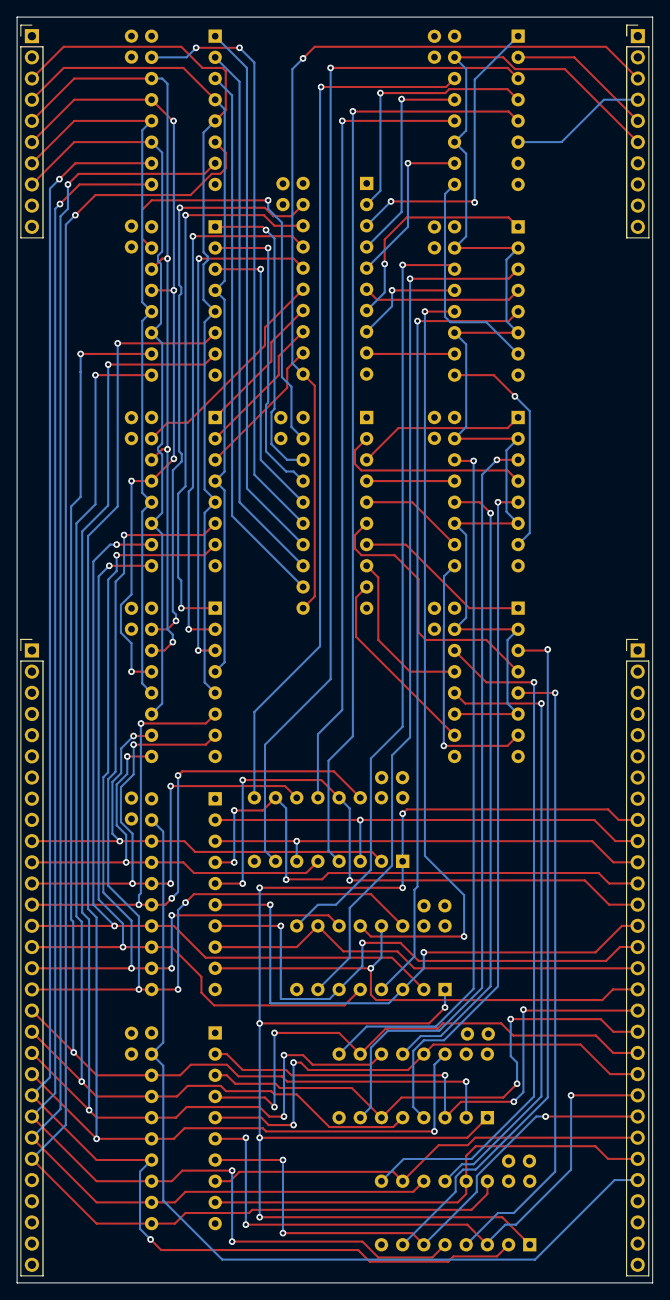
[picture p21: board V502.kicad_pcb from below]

Board: 4 copper layers, 76.2 x 151.8 mm, 36 parts (4 on the bottom side), 97 nets.

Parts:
C1, C2, C3, C4, C5, C6, C7, C8, C9, C10, C11, C12, C13, C14, C15, C16: C_Small; C_Disc_D3.0mm_W2.0mm_P2.50mm
J1, J2: Conn_01x10_Pin; PinHeader_1x10_P2.54mm_Vertical
J3, J4: Conn_01x30_Pin; PinHeader_1x30_P2.54mm_Vertical
U1, U4, U7, U10: 74LS670; DIP-16_W7.62mm
U2, U5, U8, U11: 74LS283; DIP-16_W7.62mm
U3, U6, U9, U12: 74LS157; DIP-16_W7.62mm
U13, U14: 74LS574; DIP-20_W7.62mm
U15, U16: 74LS245; DIP-20_W7.62mm

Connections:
A0: U2.5 (A1), U3.4 (Za)
A1: U2.3 (A2), U3.7 (Zb)
A2: U2.14 (A3), U3.9 (Zc)
A3: U2.12 (A4), U3.12 (Zd)
A4: U5.5 (A1), U6.4 (Za)
A5: U5.3 (A2), U6.7 (Zb)
A6: U5.14 (A3), U6.9 (Zc)
A7: U5.12 (A4), U6.12 (Zd)
A8: U8.5 (A1), U9.4 (Za)
A9: U8.3 (A2), U9.7 (Zb)
A10: U8.14 (A3), U9.9 (Zc)
A11: U8.12 (A4), U9.12 (Zd)
A12: U11.5 (A1), U12.4 (Za)
A13: U11.3 (A2), U12.7 (Zb)
A14: U11.14 (A3), U12.9 (Zc)
A15: U11.12 (A4), U12.12 (Zd)
GND: C1.2, C2.2, C3.2, C4.2, C5.2, C6.2, C7.2, C8.2, C9.2, C10.2, C11.2, C12.2, C13.2, C14.2, C15.2, C16.2, J2.1, J2.2, J2.9, J2.10, J4.1, J4.2, J4.3, J4.4, J4.5, J4.6, J4.7, J4.8, J4.9, J4.26, J4.27, J4.28, J4.29, J4.30, U1.8 (GND), U2.7 (C0), U2.8 (GND), U3.8 (GND), U3.15 (E), U4.8 (GND), U5.8 (GND), U6.8 (GND), U6.15 (E), U7.8 (GND), U8.8 (GND), U9.8 (GND), U9.15 (E), U10.8 (GND), U11.8 (GND), U12.8 (GND), U12.15 (E), U13.1 (OE), U13.10 (GND), U14.1 (OE), U14.10 (GND), U15.1 (A->B), U15.10 (GND), U16.1 (A->B), U16.10 (GND)
HLD0: U1.15 (D1), U13.19 (Q0)
HLD1: U1.1 (D2), U13.18 (Q1)
HLD2: U1.2 (D3), U13.17 (Q2)
HLD3: U1.3 (D4), U13.16 (Q3)
HLD4: U4.15 (D1), U13.15 (Q4)
HLD5: U4.1 (D2), U13.14 (Q5)
HLD6: U4.2 (D3), U13.13 (Q6)
HLD7: U4.3 (D4), U13.12 (Q7)
HLD8: U7.15 (D1), U14.19 (Q0)
HLD9: U7.1 (D2), U14.18 (Q1)
HLD10: U7.2 (D3), U14.17 (Q2)
HLD11: U7.3 (D4), U14.16 (Q3)
HLD12: U10.15 (D1), U14.15 (Q4)
HLD13: U10.1 (D2), U14.14 (Q5)
HLD14: U10.2 (D3), U14.13 (Q6)
HLD15: U10.3 (D4), U14.12 (Q7)
unnamed: U2.9 (C4), U5.7 (C0)
unnamed: U5.9 (C4), U8.7 (C0)
unnamed: U8.9 (C4), U11.7 (C0)
Ra: J2.3, U1.5 (Ra), U4.5 (Ra), U7.5 (Ra), U10.5 (Ra)
Rb: J2.4, U1.4 (Rb), U4.4 (Rb), U7.4 (Rb), U10.4 (Rb)
SELDATA: J3.9, U3.1 (S), U6.1 (S), U9.1 (S), U12.1 (S)
SRC2:0: J1.4, U2.6 (B1)
SRC2:1: J1.5, U2.2 (B2)
SRC2:2: J1.6, U2.11 (B4), U2.15 (B3), U5.2 (B2), U5.6 (B1), U5.11 (B4), U5.15 (B3), U8.2 (B2), U8.6 (B1), U8.11 (B4), U8.15 (B3), U11.2 (B2), U11.6 (B1), U11.11 (B4), U11.15 (B3)
SUM0: U2.4 (S1), U13.2 (D0)
SUM1: U2.1 (S2), U13.3 (D1)
SUM2: U2.13 (S3), U13.4 (D2)
SUM3: U2.10 (S4), U13.5 (D3)
SUM4: U5.4 (S1), U13.6 (D4)
SUM5: U5.1 (S2), U13.7 (D5)
SUM6: U5.13 (S3), U13.8 (D6)
SUM7: U5.10 (S4), U13.9 (D7)
SUM8: U8.4 (S1), U14.2 (D0)
SUM9: U8.1 (S2), U14.3 (D1)
SUM10: U8.13 (S3), U14.4 (D2)
SUM11: U8.10 (S4), U14.5 (D3)
SUM12: U11.4 (S1), U14.6 (D4)
SUM13: U11.1 (S2), U14.7 (D5)
SUM14: U11.13 (S3), U14.8 (D6)
SUM15: U11.10 (S4), U14.9 (D7)
SYSADDR0: J4.10, U1.10 (Q1), U3.2 (I0a), U15.18 (B0)
SYSADDR1: J4.11, U1.9 (Q2), U3.5 (I0b), U15.17 (B1)
SYSADDR2: J4.12, U1.7 (Q3), U3.11 (I0c), U15.16 (B2)
SYSADDR3: J4.13, U1.6 (Q4), U3.14 (I0d), U15.15 (B3)
SYSADDR4: J4.14, U4.10 (Q1), U6.2 (I0a), U15.14 (B4)
SYSADDR5: J4.15, U4.9 (Q2), U6.5 (I0b), U15.13 (B5)
SYSADDR6: J4.16, U4.7 (Q3), U6.11 (I0c), U15.12 (B6)
SYSADDR7: J4.17, U4.6 (Q4), U6.14 (I0d), U15.11 (B7)
SYSADDR8: J4.18, U7.10 (Q1), U9.2 (I0a), U16.18 (B0)
SYSADDR9: J4.19, U7.9 (Q2), U9.5 (I0b), U16.17 (B1)
SYSADDR10: J4.20, U7.7 (Q3), U9.11 (I0c), U16.16 (B2)
SYSADDR11: J4.21, U7.6 (Q4), U9.14 (I0d), U16.15 (B3)
SYSADDR12: J4.22, U10.10 (Q1), U12.2 (I0a), U16.14 (B4)
SYSADDR13: J4.23, U10.9 (Q2), U12.5 (I0b), U16.13 (B5)
SYSADDR14: J4.24, U10.7 (Q3), U12.11 (I0c), U16.12 (B6)
SYSADDR15: J4.25, U10.6 (Q4), U12.14 (I0d), U16.11 (B7)
SYSCLK: J1.3, U13.11 (Cp), U14.11 (Cp)
SYSDATA0: J3.10, U3.3 (I1a), U15.2 (A0)
SYSDATA1: J3.11, U3.6 (I1b), U15.3 (A1)
SYSDATA2: J3.12, U3.10 (I1c), U15.4 (A2)
SYSDATA3: J3.13, U3.13 (I1d), U15.5 (A3)
SYSDATA4: J3.14, U6.3 (I1a), U15.6 (A4)
SYSDATA5: J3.15, U6.6 (I1b), U15.7 (A5)
SYSDATA6: J3.16, U6.10 (I1c), U15.8 (A6)
SYSDATA7: J3.17, U6.13 (I1d), U15.9 (A7)
SYSDATA8: J3.18, U9.3 (I1a), U16.2 (A0)
SYSDATA9: J3.19, U9.6 (I1b), U16.3 (A1)
SYSDATA10: J3.20, U9.10 (I1c), U16.4 (A2)
SYSDATA11: J3.21, U9.13 (I1d), U16.5 (A3)
SYSDATA12: J3.22, U12.3 (I1a), U16.6 (A4)
SYSDATA13: J3.23, U12.6 (I1b), U16.7 (A5)
SYSDATA14: J3.24, U12.10 (I1c), U16.8 (A6)
SYSDATA15: J3.25, U12.13 (I1d), U16.9 (A7)
VCC: C1.1, C2.1, C3.1, C4.1, C5.1, C6.1, C7.1, C8.1, C9.1, C10.1, C11.1, C12.1, C13.1, C14.1, C15.1, C16.1, J1.1, J1.2, J1.7, J1.8, J1.9, J1.10, J3.1, J3.2, J3.3, J3.4, J3.5, J3.6, J3.7, J3.8, J3.27, J3.28, J3.29, J3.30, U1.16 (VCC), U2.16 (VCC), U3.16 (VCC), U4.16 (VCC), U5.16 (VCC), U6.16 (VCC), U7.16 (VCC), U8.16 (VCC), U9.16 (VCC), U10.16 (VCC), U11.16 (VCC), U12.16 (VCC), U13.20 (VCC), U14.20 (VCC), U15.20 (VCC), U16.20 (VCC)
Wa: J2.5, U1.14 (Wa), U4.14 (Wa), U7.14 (Wa), U10.14 (Wa)
Wb: J2.6, U1.13 (Wb), U4.13 (Wb), U7.13 (Wb), U10.13 (Wb)
~AtoD: J3.26, U15.19 (CE), U16.19 (CE)
~Er: J2.8, U1.11 (~Er), U4.11 (~Er), U7.11 (~Er), U10.11 (~Er)
~Ew: J2.7, U1.12 (~Ew), U4.12 (~Ew), U7.12 (~Ew), U10.12 (~Ew)

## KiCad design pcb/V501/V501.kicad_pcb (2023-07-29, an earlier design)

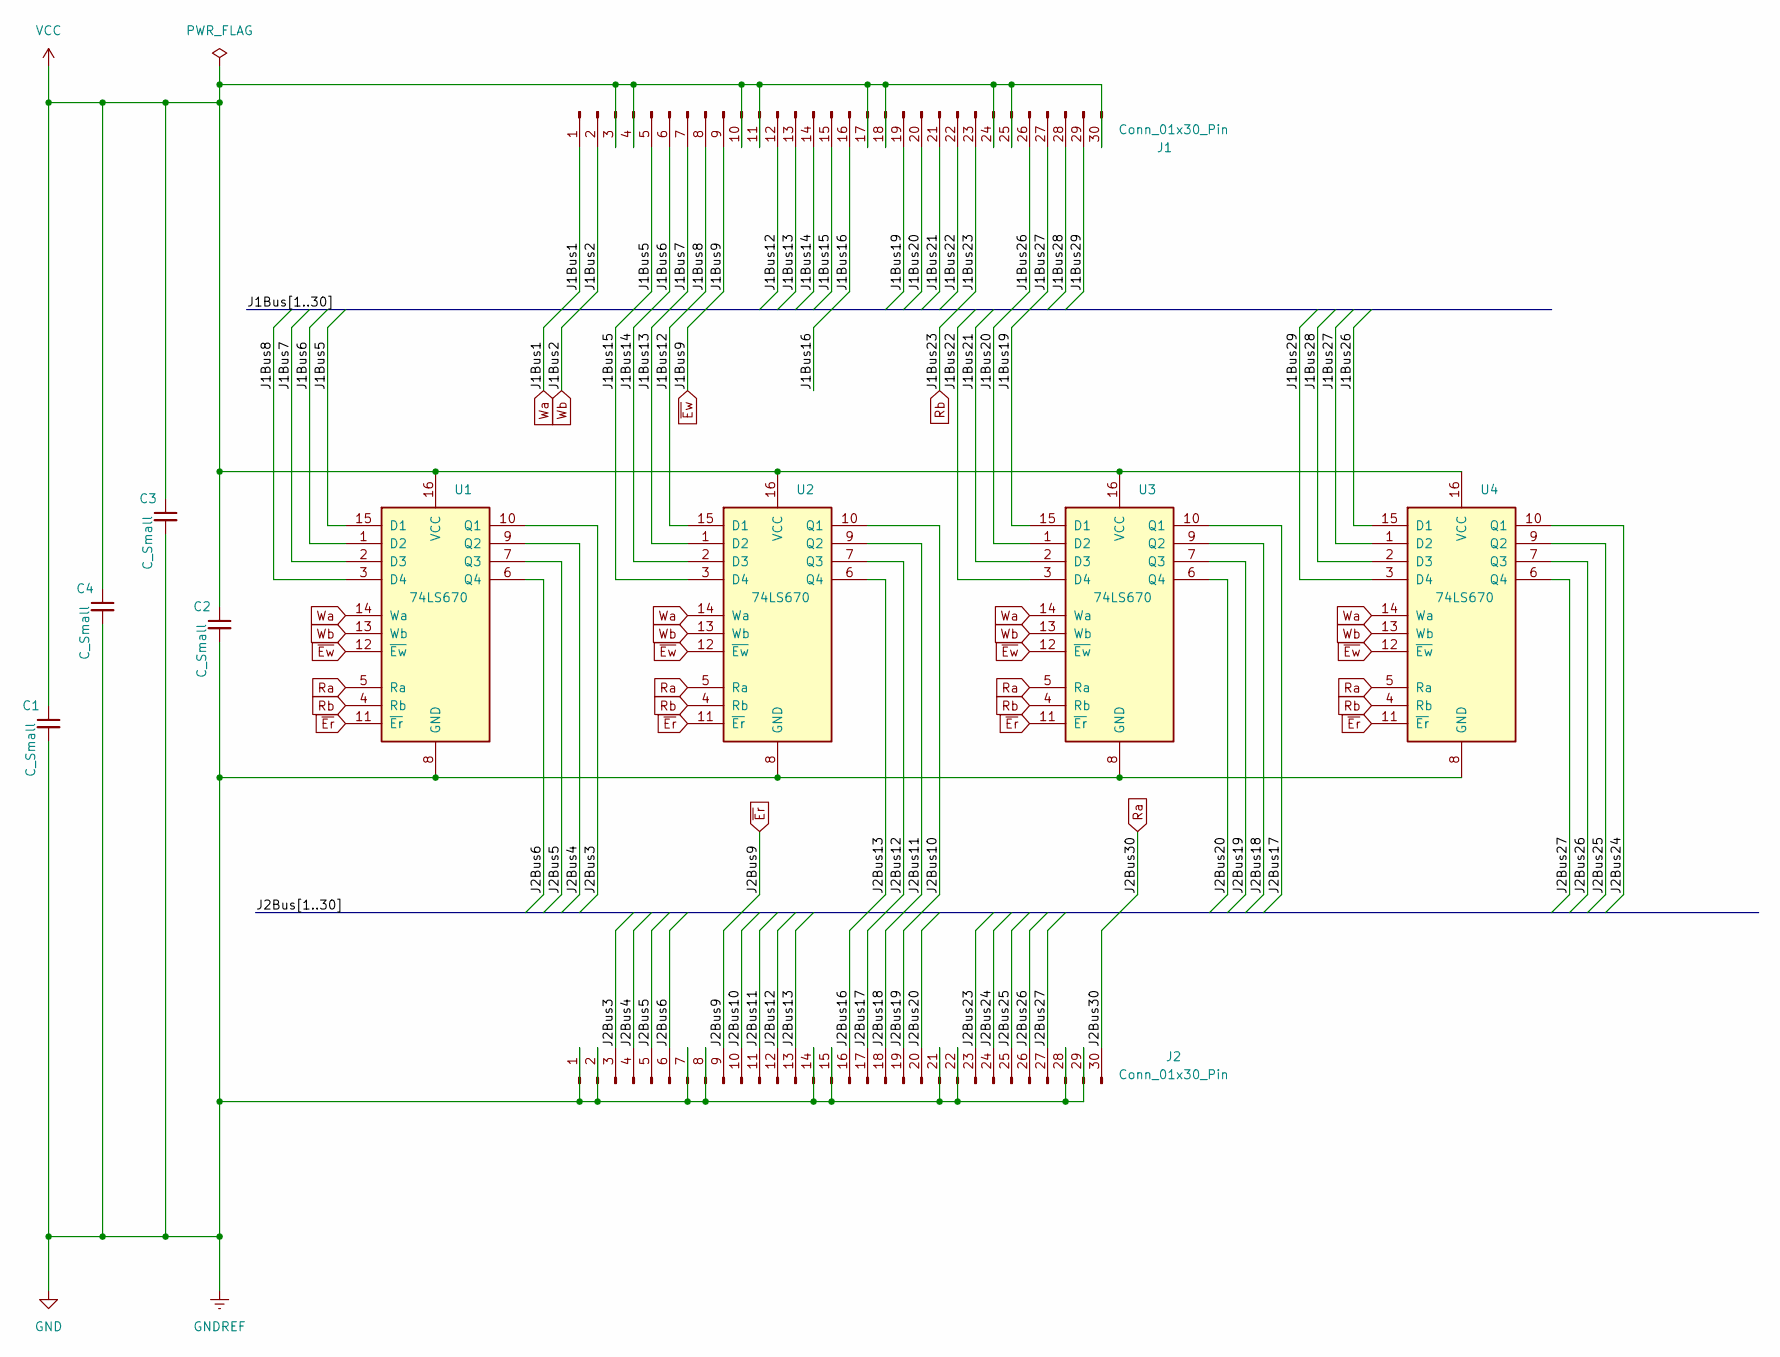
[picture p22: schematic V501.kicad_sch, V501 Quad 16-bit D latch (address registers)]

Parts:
C1, C2, C3, C4: C_Small; C_Disc_D5.0mm_W2.5mm_P2.50mm
J1, J2: Conn_01x30_Pin; PinHeader_1x30_P2.54mm_Vertical
U1, U2, U3, U4: 74LS670; DIP-16_W7.62mm

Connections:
/J1Bus5: J1.5, U1.15 (D1)
/J1Bus6: J1.6, U1.1 (D2)
/J1Bus7: J1.7, U1.2 (D3)
/J1Bus8: J1.8, U1.3 (D4)
/J1Bus12: J1.12, U2.15 (D1)
/J1Bus13: J1.13, U2.1 (D2)
/J1Bus14: J1.14, U2.2 (D3)
/J1Bus15: J1.15, U2.3 (D4)
/J1Bus16: J1.16
/J1Bus19: J1.19, U3.15 (D1)
/J1Bus20: J1.20, U3.1 (D2)
/J1Bus21: J1.21, U3.2 (D3)
/J1Bus22: J1.22, U3.3 (D4)
/J1Bus26: J1.26, U4.15 (D1)
/J1Bus27: J1.27, U4.1 (D2)
/J1Bus28: J1.28, U4.2 (D3)
/J1Bus29: J1.29, U4.3 (D4)
/J2Bus3: J2.3, U1.10 (Q1)
/J2Bus4: J2.4, U1.9 (Q2)
/J2Bus5: J2.5, U1.7 (Q3)
/J2Bus6: J2.6, U1.6 (Q4)
/J2Bus10: J2.10, U2.10 (Q1)
/J2Bus11: J2.11, U2.9 (Q2)
/J2Bus12: J2.12, U2.7 (Q3)
/J2Bus13: J2.13, U2.6 (Q4)
/J2Bus16: J2.16
/J2Bus17: J2.17, U3.10 (Q1)
/J2Bus18: J2.18, U3.9 (Q2)
/J2Bus19: J2.19, U3.7 (Q3)
/J2Bus20: J2.20, U3.6 (Q4)
/J2Bus23: J2.23
/J2Bus24: J2.24, U4.10 (Q1)
/J2Bus25: J2.25, U4.9 (Q2)
/J2Bus26: J2.26, U4.7 (Q3)
/J2Bus27: J2.27, U4.6 (Q4)
GND: C1.2, C2.2, C3.2, C4.2, J2.1, J2.2, J2.7, J2.8, J2.14, J2.15, J2.21, J2.22, J2.28, J2.29, U1.8 (GND), U2.8 (GND), U3.8 (GND), U4.8 (GND)
Ra: J2.30, U1.5 (Ra), U2.5 (Ra), U3.5 (Ra), U4.5 (Ra)
Rb: J1.23, U1.4 (Rb), U2.4 (Rb), U3.4 (Rb), U4.4 (Rb)
VCC: C1.1, C2.1, C3.1, C4.1, J1.3, J1.4, J1.10, J1.11, J1.17, J1.18, J1.24, J1.25, J1.30, U1.16 (VCC), U2.16 (VCC), U3.16 (VCC), U4.16 (VCC)
Wa: J1.1, U1.14 (Wa), U2.14 (Wa), U3.14 (Wa), U4.14 (Wa)
Wb: J1.2, U1.13 (Wb), U2.13 (Wb), U3.13 (Wb), U4.13 (Wb)
~Er: J2.9, U1.11 (~Er), U2.11 (~Er), U3.11 (~Er), U4.11 (~Er)
~Ew: J1.9, U1.12 (~Ew), U2.12 (~Ew), U3.12 (~Ew), U4.12 (~Ew)

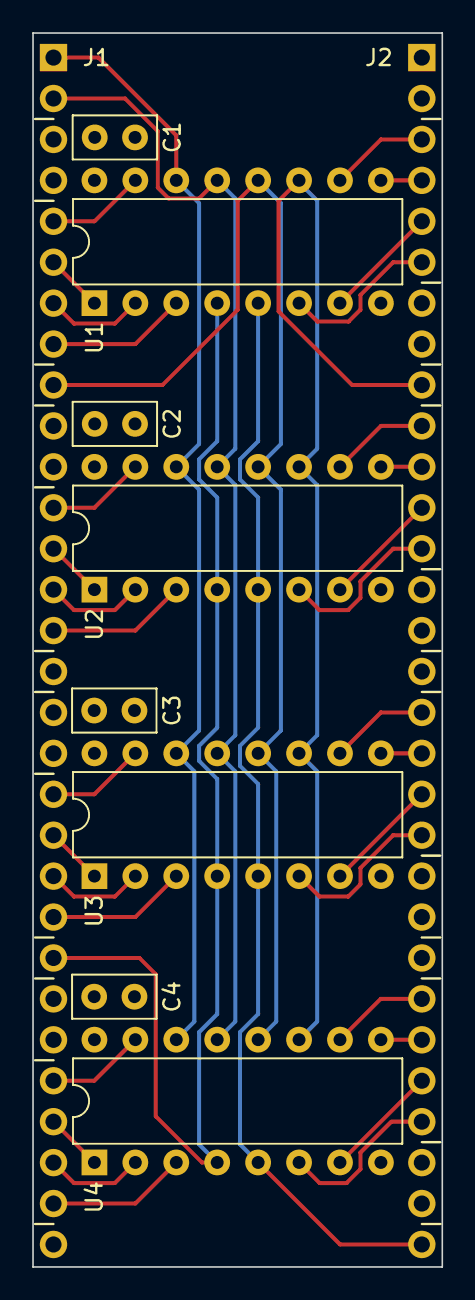
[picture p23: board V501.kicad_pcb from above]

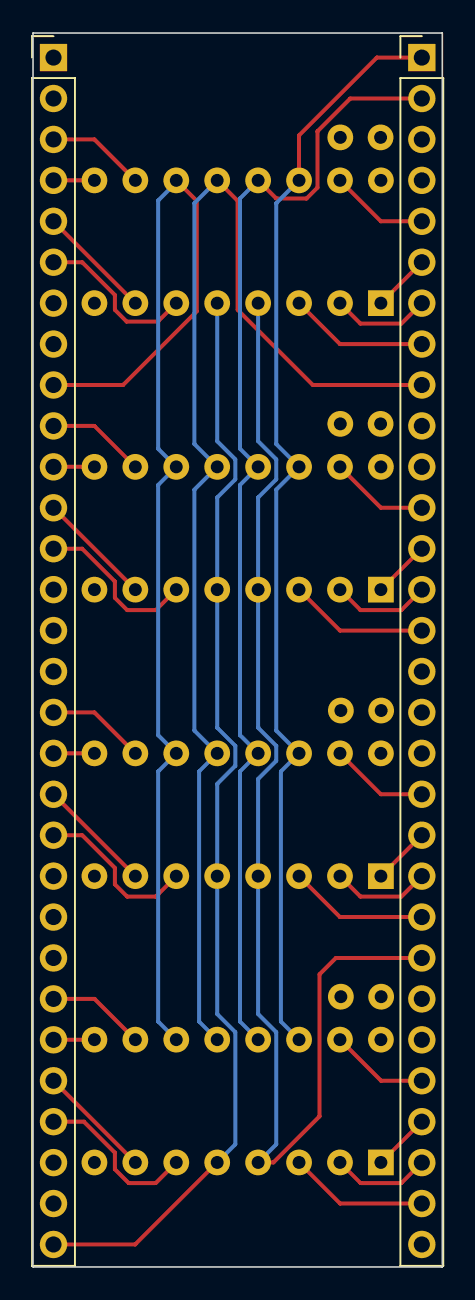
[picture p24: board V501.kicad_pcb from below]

Board: 4 copper layers, 25.4 x 76.6 mm, 10 parts (2 on the bottom side), 40 nets.

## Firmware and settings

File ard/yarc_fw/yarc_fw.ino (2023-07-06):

// Copyright (c) Jeff Berkowitz 2021. All rights reserved.
// Downloader firmware for Yet Another Retro Computer - YARC
//
// The Arduino IDE has peculiar rules about multiple file programs.
// Separate compilation is only allowed for "library modules", which
// are less convenient to develop than "ordinary" firmware.
//
// But the IDE allows explicit include files, so the best compromise
// is to put most of the code in .h files and include them here. So
// if we were naive, all symbols would be equally visible throughout
// the code. We could live with this, but it would be annoying. We
// implement a (slightly) better solution.
//
// We have two kinds of files: _decls files which contain only forward
// declarations of functions intended to be public, and _task files
// containing code. Each task file may define a C++11 namespace
// conventionally named TaskPrivate, e.g. SerialPrivate, etc., for
// its private functions and data. The task's public methods must
// explicitly reference the private namespace, which is annoying,
// but so must any other task that wants to breaks the visibility
// rules, and the compiler enforces that. It's a sufficient answer.
//
// Since the declaration files are just forwards, their order doesn't
// matter; and once they are all included first, the order of tasks
// doesn't matter either. So in theory there are no ordering
// dependencies except putting all the declaration includes before
// all the task includes.
//
// There is a tiny "task executor" for the "tasks". But don't be fooled;
// the task abstraction is just a way of structuring the main loop.
// There are no trixie preemption schemes, no interrupt code, nothing
// like that. Just a main loop that runs through all the task bodies
// as quickly as possible. In fact, "tasks" don't need to have bodies
// or even init functions; the logging "task" is just a couple of public
// functions and some private data.
//
// We do concede to including the task runner last so we don't have
// to forward-declare all the task init and body functions. We could
// instead have a registration scheme, but this approach allows us to
// put the task table in ROM (see task_runner.h). We make similar use
// of PROGMEM for data tables in several of the task modules.

typedef unsigned short ushort;

#include "task_decls.h"
#include "port_decls.h"
#include "small_task_decls.h"
#include "cost_decls.h"
#include "yarc_decls.h"

#include "port_utils.h"
#include "small_tasks.h"
#include "serial_task.h"
#include "port_task.h"
#include "cost_task.h"
#include "yarc_utils.h"

#include "task_runner.h"

void setup() {
  InitTasks();
}

// Main body - delegate to task runner
void loop() {
  for (;;) {
    RunTasks();
  }
}

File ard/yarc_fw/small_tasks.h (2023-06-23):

// Copyright (c) Jeff Berkowitz 2021. All rights reserved.
// This is the heartbeat task. Its produces a periodic log message.

namespace HeartbeatPrivate {
  
  #define HB_DELAY_MILLIS 7993
  
  #define HB_MS_PER_SEC 1000L
  #define HB_MS_PER_MIN (60L * HB_MS_PER_SEC)
  #define HB_MS_PER_HOUR (60L * HB_MS_PER_MIN)
  #define HB_MS_PER_DAY (24L * HB_MS_PER_HOUR)
  
  unsigned long hbLastHeartbeatMillis = 0;
  unsigned long hbTaskIterations = 0;
  
  // Queued for callback by the heartbeat task, called back from the
  // serial task next time the host requests a message.
  int heartbeatMessageCallback(char *bp, int bmax) {
    int days = 0, hours = 0, minutes = 0, seconds = 0, ms = 0;
    
    unsigned long now = millis();
    unsigned long elapsed = now - hbLastHeartbeatMillis;
    hbLastHeartbeatMillis = now;
  
    ms = now % HB_MS_PER_SEC;
    now -= ms;
    if (now > 0) {
      long n = now % HB_MS_PER_MIN;
      now -= n;
      seconds = n / HB_MS_PER_SEC;
    }
    if (now > 0) {
      long n = now % HB_MS_PER_HOUR;
      now -= n;
      minutes = n / HB_MS_PER_MIN;
    }
    if (now > 0) {
      long n = now % HB_MS_PER_DAY;
      now -= n;
      hours = n / HB_MS_PER_HOUR;
    }
    if (now > 0) {
      long n = now % HB_MS_PER_DAY;
      days = n / HB_MS_PER_DAY;
    }
  
    // snprintf_P returns "...the number of characters that would have been written to s if there were enough space."
    // http://www.nongnu.org/avr-libc/user-manual/group__avr__stdio.html#ga53ff61856759709eeceae10aaa10a0a3
    int result = snprintf_P(bp, bmax, PSTR("Up %02d:%02d:%02d:%02d.%03d, about %ld task/ms, max %dms"),
               days, hours, minutes, seconds, ms, hbTaskIterations / elapsed, hbLongestTask);
    if (result > bmax) result = bmax;
    hbTaskIterations = 0;
    hbLongestTask = 1;
    return result;
  }
}

// Public interface to heartbeat task

// The task runner sets this to the longest task execution between
// heartbeats, and the heartbeat code (above) sets it back to 1.
// The value of 1 isn't interesting because milliseconds can click
// over from N to N+1 during any task execution.
int hbLongestTask = 1;

// The HB task tracks iterations so it can log the number of task
// executions in the recent past.
void inline hbIncIterationCount() {
  HeartbeatPrivate::hbTaskIterations++;
}

int heartbeatTask() {
  logQueueCallback(HeartbeatPrivate::heartbeatMessageCallback);
  return HB_DELAY_MILLIS;  
}

// Management task for Nano's on-board LED
// Symbol prefixes: led, LED_

// This task plays one of a few prespecified on-off patterns on the
// onboard LED. The current pattern is always played to completion
// before starting the next. The next pattern played will be the same
// as the current pattern unless a call to set a different pattern is
// made by some other part of the code. The queue of pending patterns
// is one-deep; if multiple calls to set the next pattern occur, the
// last call wins.

namespace LedPrivate {
  
  const byte *ledCurrentPattern;
  const byte *ledNextPattern;
  int ledPatternIndex;
  
  #define LED_PIN 13 // all Arduinos
  
  // These macros need to be used with care. The duration is encoded in
  // the high-order 7 bits of the byte and the state of the LED in the
  // LSB. So the maximum duration is (0xFF >> 1) == 127 ticks or 1270ms
  // so long as the tick frequency is 100Hz (period 10ms).
  
  #define LED_TICK_INTERVAL_MILLIS 10
  #define LED_MILLIS_TO_TICKS(n) ((n) / LED_TICK_INTERVAL_MILLIS)
  #define LED_TICKS_TO_MILLIS(n) ((n) * LED_TICK_INTERVAL_MILLIS)
  #define LED_ON(ms) ((LED_MILLIS_TO_TICKS(ms) << 1) | 1)
  #define LED_OFF(ms) ((LED_MILLIS_TO_TICKS(ms) << 1) & 0xFE)
  #define LED_END_PATTERN 0
  
  const PROGMEM byte ledStandardHeartbeat[] = {LED_ON(700), LED_OFF(700), LED_END_PATTERN};
  
  #define LED_DIT LED_OFF(150),LED_ON(150)
  #define LED_DAH LED_OFF(250),LED_ON(500)
  #define LED_SPACE LED_OFF(250)
  #define LED_PAUSE LED_OFF(750)
  
  const PROGMEM byte ledSos[] = { LED_DIT, LED_DIT, LED_DIT, LED_SPACE, LED_DAH, LED_DAH, LED_DAH,
                          LED_SPACE, LED_DIT, LED_DIT, LED_DIT, LED_PAUSE, LED_END_PATTERN };
}

// public funcions for LED

void ledPlayStandardHeartbeat() {
  LedPrivate::ledNextPattern = LedPrivate::ledStandardHeartbeat;
}

void ledPlaySos() {
  LedPrivate::ledNextPattern = LedPrivate::ledSos;
}

int ledTask() {
  byte todo = pgm_read_byte_near(&LedPrivate::ledCurrentPattern[LedPrivate::ledPatternIndex]);
  if (todo == LED_END_PATTERN) {
    LedPrivate::ledPatternIndex = 0;
    LedPrivate::ledCurrentPattern = LedPrivate::ledNextPattern;
    todo = pgm_read_byte_near(&LedPrivate::ledCurrentPattern[LedPrivate::ledPatternIndex]);
  }
  LedPrivate::ledPatternIndex++;
  digitalWrite(LED_PIN, todo & 1);
  return LED_TICKS_TO_MILLIS(todo >> 1);
}

void ledInit() {
  pinMode(LED_PIN, OUTPUT);
  digitalWrite(LED_PIN, LOW);
  LedPrivate::ledCurrentPattern = LedPrivate::ledStandardHeartbeat;
  LedPrivate::ledNextPattern = LedPrivate::ledStandardHeartbeat;
  LedPrivate::ledPatternIndex = 0;
}

// This is the logging task.
// 
// The logger should not be used for chit-chat (Thank You ken & dmr)
//
// Lack of foresight: this is the infrastructure for making general
// requests to the Mac. The default request is to log a message; this
// is indicated because the request starts with a letter or number,
// specifically any character except these: '!', '#', or '$'.
//
// When the first byte of the messages is one of the characters in
// that set, it indicates some non-logging request to the Mac. Currently
// only '$' is used for requests and '!' for responses.
//
// The prefix on this identifiers in this file will eventually be
// generalized from "log" to "req" for request...lack of foresight.
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

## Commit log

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2022-04-14 Add some memory documentation and revise memory read logic
    [Memory.kicad_sch, RAM-16.fzz]
2022-04-17 Add gitignore. Update memory read signal. Update memory transceiver direction control. Many routing improvements.
    [Memory.kicad_sch, RAM-16.fzz]
2022-04-20 Clean up layout. Add layout for microcode engine.
    [RAM-16.fzz, microcode.fzz]
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2022-04-25 Minor wiring update. Begin move to Cobra-based host CLI.
    [RAM-16.fzz]
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2022-05-07 Wiring change on RAM and additional work on assembler
    [RAM-16.fzz]
2022-06-05 FW advances, but still loops during HW reset. Major addition to assembler. Minor changes to FRAM Fritzing layout (RAM control wiring is complete).
    [RAM-16.fzz]
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2022-06-19 Firmware changes, microcode engine layout, and ISA doc improvements.
    [microcode.fzz]
2022-06-19 Fix a couple of errors
2022-06-21 Much work on microcode engine layout (.fzz) and found bug in lexer pushback.
    [microcode.fzz]
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2022-07-05 Add microcode engine to KiCad. Minor updates to README.
    [Memory.kicad_sch, MicrocodeEngine.kicad_sch, YARC.kicad_sch]
2022-07-05 Update README and docs. Progress on KiCad ucode schematic. Moved yasm code.
    [MicrocodeControl.kicad_sch, MicrocodeEngine.kicad_sch, MicrocodeTransceivers.kicad_sch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]
2022-07-06 Significant progress on microcode schematic. Minor improvements to MemorySystem.md.
    [MicrocodeControl.kicad_sch, MicrocodeEngine.kicad_sch, MicrocodeTransceivers.kicad_sch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]
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2022-07-22 Fixes to assembler. New yasm code. Added HC670 to Fritzing. Add ALU, Registers, and Stacks sketches.
    [ALU.fzz, Registers.fzz, Stacks.fzz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]
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2022-08-17 More work on microcode (both yasm and Fritzing)
    [microcode.fzz]
2022-08-19 Add MEM_EN# fix to arch.yasm, KiCad, and Fritzing
    [Memory.kicad_sch, RAM-16.fzz, YARC.kicad_sch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]
2022-08-19 (Oops, forgot to save and quit; redo:) Add MEM_EN# fix to arch.yasm, KiCad, and Fritzing
    [RAM-16.fzz, microcode.fzz]
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2022-08-28 Nano IR clock and mem enable changes documented in Ki, Ftz, and port_task.h
    [Downloader.fzz, DownloaderCore.kicad_sch, Memory.kicad_sch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]
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2022-09-08 Major cleanup of port_task.h (again) and minor changes to design
    [ALU.fzz, microcode.fzz]
2022-09-09 Fix another couple of bus in ard code. Add code for testing microcode control register. Remove tabs from yasm files.
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2022-09-19 Changes for UCR support. Not debugged. Minor updates to microcode engine layout.
    [microcode.fzz]
2022-09-20 In the midst of implementing service requests from Nano
    [Registers.fzz]
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2022-09-30 Fixing wiring diagram and implement writeToK()
    [MicrocodeControl.kicad_sch, MicrocodeEngine.kicad_sch, YARC.kicad_sch]
2022-10-01 Implement writeBytesToSlice() and update the microcode layout in ftz with latest
    [microcode.fzz]
2022-10-04 Implement port task for testing microcode slice 0
    [microcode.fzz]
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2022-10-08 Add details to register design and add third ucode slice to test task
    [Registers.fzz]
2022-10-09 Three new parts and two new sketches in Fritzing
    [Flags.fzz, NorthAndSouthCentral.fzz, Registers.fzz]
2022-10-12 Expand ucode RAM test to 4 slices. Much work in KiCad.
    [ConstRegsAndClocks.kicad_sch, GeneralRegisters.kicad_sch, MicrocodeControl.kicad_sch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]
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2022-11-18 Updates to ISA doc. Matching corrections to arch.yasm. Flags layout in Ftz.
    [Flags.fzz, SouthCentral.kicad_sch, YARC.kicad_sch]
2022-11-20 Additional wiring updates. Add SetK protocol command and remove much of breakpoint logic from protocol.
    [NorthAndSouthCentral.fzz, Registers.fzz, SouthCentral.kicad_sch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]
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2022-12-01 Some fixes relating to the bit ordering issue
    [ConstRegs.kicad_sch, Registers.fzz, YARC.kicad_sch]
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2022-12-06 Fix additional wiring errors via the firmware
    [port_utils.h]
2022-12-07 Fix UCR wiring error in software. Fix microcode assembler and dump code. Minor updates to microcode (yasm).
    [microcode.fzz]
2022-12-12 More wiring fixes and firmware development
    [Memory.kicad_sch, RAM-16.fzz, Registers.fzz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]
2022-12-23 All the changes related to the mid-December 2022 K register problem
    [KludgeSpace.kicad_sch, Memory.kicad_sch, MicrocodeControl.kicad_sch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]
2023-01-07 Assign part labels (U-numbers) in KiCad and start adding them to Fritzing layouts
    [ConstRegs.kicad_sch, GeneralRegisters.kicad_sch, KludgeSpace.kicad_sch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]
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2023-01-17 Nano FW: fix the logging issue and flesh out the memory test
    [cost_task.h]
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2023-01-27 Finally debugged the 16-bit memory test. No hardware issues.
    [cost_task.h]
2023-02-05 Add register enable to MCR. Corrections and cleanups.
    [ConstRegs.kicad_sch, KludgeSpace.kicad_sch, NorthCentral.kicad_sch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]
2023-02-11 Schematic for flags. Also ongoing improvements to register test (as yet incomplete)
    [ALU.fzz, FlagLogic.kicad_sch, YARC.kicad_sch]
2023-02-17 Flags development and implement memory fix. Firmware not updated to match the memory fix.
    [ClockDownloaderExtension.kicad_sch, FlagLogic.kicad_sch, Memory.kicad_sch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]
2023-02-17 New memory control logic passes a basic test. Firmware loops after reset running the test.
    [Memory.kicad_sch, YARC.kicad_sch]
2023-02-19 Remove unnecessary code from startup. Comment out long startup test. Fix the mem16 COST test for the new microcode.
    [cost_task.h]
2023-02-19 Comment out broken startup code and implement memBasicTest in COST tests
    [cost_task.h]
2023-02-24 Major changes to ALU, Flags, and add new ALU controls schematic
    [ALU.kicad_sch, ALUControls.kicad_sch, ConstRegs.kicad_sch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]
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2023-02-28 ALU schematic checking complete. Ready to start layout.
    [ALU.kicad_sch, ALUControls.kicad_sch, DownloaderCore.kicad_sch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]
2023-03-05 Improvements to ALU and Flags schematic. Begin work on layout.
    [ALU.fzz, ALUControls.kicad_sch, NorthCentral.kicad_sch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]
2023-03-08 Ongoing development of ALU and Flags. Construction start.
    [ALU.fzz, ALUControls.kicad_sch, ConstRegs.kicad_sch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]
2023-03-10 Various corrections and minor improvements
    [ALU.fzz, ALUControls.kicad_sch, ConstRegs.kicad_sch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]
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2023-03-14 Fix - add microcode RAM enables to schematic
    [MicrocodeControl.kicad_sch, MicrocodeEngine.kicad_sch]
2023-03-14 Redesign of ALU control logic
    [ALU.kicad_sch, ALUControls.kicad_sch, FlagLogic.kicad_sch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]
2023-03-18 Yet more cleanup on ALU and flags design
    [ALU.fzz, ALU.kicad_sch, ALUControls.kicad_sch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]
2023-03-24 Ongoing corrections and improvements
    [ALU.kicad_sch, FlagLogic.kicad_sch, Flags.fzz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]
2023-03-24 Complete replacement of old code with new verifying WriteMicrocode() API
    [cost_task.h]
2023-03-25 Add a reset message
    [small_tasks.h]
2023-03-29 Add the ACN mini-bus which can come from the instruction bits 11:8 or from the microcode bits 23:20. It selects the ALU operation and the condition codes.
    [ALU.kicad_sch, FlagLogic.kicad_sch, MicrocodeTransceivers.kicad_sch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]
2023-03-29 Draw in a few more wires on the (incomplete) Flags layout
    [Flags.fzz]
2023-03-30 Correct unit numbers on 7486 in Flags section
    [FlagLogic.kicad_sch, YARC.kicad_sch]
2023-03-30 Discovered that ACN mux was already drawn on another sheet of the schematic - fixed. Added ACN control bit to microcode. Ongoing cleanup: replaced acronym RSW with RCW in assembly language.
    [MicrocodeTransceivers.kicad_sch, SouthCentral.kicad_sch, YARC.kicad_sch]
2023-04-01 Fix schematic error in <= gate. Cleanup signal naming. Fix subtle issue with carry in signal.
    [ALU.fzz, ALUControls.kicad_sch, FlagLogic.kicad_sch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]
2023-04-02 Additional corrections found during wiring
    [FlagLogic.kicad_sch, Flags.fzz, YARC.kicad_sch]
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2023-04-05 Ongoing corrections. Document the Nano's sysbus enable control for the first time.
    [ALUControls.kicad_sch, KludgeSpace.kicad_sch, MicrocodeControl.kicad_sch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]
2023-04-07 Start of final wiring. Relocate U135 and U136 close to clock distribution line in Flags circuit.
    [ALU.fzz, ALUControls.kicad_sch, Flags.fzz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]
2023-04-11 Implement run and stop COST serial commands. Correct SetK serial command. Remove unimplemeted stop and start clock serial commands. Protocol now version 7. Minor changes to hardware design.
    [ALU.fzz, FlagLogic.kicad_sch]
2023-04-13 Interim checkin. Many changes in support of COST test for flags. Flags test is currently failing for unknown reasons.
    [cost_task.h]
2023-04-19 Minor corrections to signal naming in memory controller
    [ConstRegs.kicad_sch, RAM-16.fzz]
2023-04-20 Fix another microprogramming problem in WriteReg(). Prevent the same problem in ReadReg(). Remove stop point and reenable COST tests. Clean up commented-out code.
    [cost_task.h]
2023-04-20 Remove -w from gcc, which was inhibiting all warnings. Fix the resulting warnings. Most serious were in the serial task, where there were some returns without arguments where the value was used.
    [cost_task.h, serial_task.h, small_tasks.h]
2023-04-20 Change warnings setting to 'More' and fix two additional minor warnings (two unused variables).
    [cost_task.h]
2023-04-26 Ongoing corrections and improvements. No major additions.
    [ALU.fzz, ALU.kicad_sch, ALUControls.kicad_sch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]
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2023-05-04 Continuing corrections (only - no new functionality)
    [DownloaderCore.kicad_sch, FlagLogic.kicad_sch, KludgeSpace.kicad_sch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]
2023-05-04 Interim commit with wiring complete. Partial implementation of ALU RAM read/write. Flags test in COST is failing due to HW updates.
    [port_utils.h, serial_task.h]
2023-05-10 Major changes in pursuit of command handler simplification. Protocol now honored with respect to fixed responses. Some command handlers need to be updated and are commented out. Nano logging works an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
    [serial_task.h, small_tasks.h]
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2023-05-13 Overrun problem addressed. Memory write performance improved. Obsolete code deleted.
    [serial_task.h]
2023-05-16 Add ALU RAM read and write protocol commands. Improve COST test for ALU RAM and reduce intertest delay. Improve argument verification; fix boundary checks against END_MEM.
    [cost_task.h, serial_task.h]
2023-05-17 Document ALU RAM write clock delay line (fix for ALU RAM write issue)
    [NorthCentral.kicad_sch, YARC.kicad_sch]
2023-05-17 Bug fixes for downloader. Downloader complete, but very slow.
    [serial_task.h]
2023-05-21 Modest reorganization of reset code. Implement run, stop, get bus interface register, and do single cycle commands to YARC
    [serial_task.h]
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2023-05-28 Implement ir0_en microcode bit to fix design error with JMP
    [ConstRegs.kicad_sch, MicrocodeControl.kicad_sch, MicrocodeTransceivers.kicad_sch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]
2023-06-02 Fix download bug (sending incorrect opcode byte). Leave commented-out microcode slice verify and print code.
2023-06-04 Implement ClockCtl (0xE4) on the host side and fix a bug on the Nano side.
    [serial_task.h]
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2023-06-14 Large commit. Document two hardware changes to microcode controls. Adapt Nano firmware to these changes. Significantly simplify initialization logic and make it more consistent about reset.
    [KludgeSpace.kicad_sch, MicrocodeControl.kicad_sch, MicrocodeEngine.kicad_sch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]
2023-06-15 Cleanups on the way to first execution - no significant functional changes
    [Memory.kicad_sch, MicrocodeControl.kicad_sch, RAM-16.fzz]
2023-06-17 Add delay line for general register write signal. Minor corrections and cleanups.
    [ALUControls.kicad_sch, ConstRegs.kicad_sch, GeneralRegisters.kicad_sch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]
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2023-06-26 Protocol version 11. Add debug command to serial spec. Update protogen. Implement debug command db 1 in both host software and Nano firmware. Fix bug where ReadMem16() and WriteMem16() were being cal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
    [serial_task.h]
2023-06-26 Add support for fixing the value of fields in the instruction using syntax .meta=value in the .opcode definition. Ongoing development of assembly language instruction set.
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2023-07-01 Add a test for WriteCheckALU(). Unlike other COST tests, it panics if it fails.
    [cost_task.h]
2023-07-05 Add a COST test to expose newly discovered memory corruption problem. Writing to address 0x2000 (specifically) changes the memory at location 0.
    [cost_task.h]
2023-07-06 Add very involved memory checker in search for the 0x2000 problem. Also define byte and ushort as types unsigned char and unsigned short.
    [cost_task.h, yarc_fw.ino]
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2023-07-29 This directory may be a result of upgrading to KiCad v7.
    [ALU.kicad_sch, ALUControls.kicad_sch, ClockDownloaderExtension.kicad_sch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]
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2023-07-29 Add V501, an 84-style module with four 16-bit registers (sadly, really latches)
    [V501-B_Cu.gbr, V501-B_Mask.gbr, V501-B_Paste.gbr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]
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2023-08-04 V503 board is fully routed. ERC and DRC pass.
    [LowerHalf.kicad_sch, UpperHalf.kicad_sch, V503.kicad_pcb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]
2023-08-04 Clean up clearances, run DRC and ERC, and generate Gerbers. Tape out.
    [LowerHalf.kicad_sch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]
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2023-08-06 Removed about 2/3 of 2300+ errors from the ERC
    [ALU.kicad_sch, ALUControls.kicad_sch, ClockDownloaderExtension.kicad_sch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]
2023-08-09 Ongoing fixes for ERC errors
    [ALU.kicad_sch, ALUControls.kicad_sch, ClockDownloaderExtension.kicad_sch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]
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2023-08-14 Additional minor corrections. ERC clean.
    [ALUControls.kicad_sch, FlagLogic.kicad_sch, KludgeSpace.kicad_sch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]
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2023-09-24 Revise SET# logic for LD_UCODE_CTR#. Fix minor errors with no functional consequences (schematic didn't match reality)
    [ALUControls.kicad_sch, DownloaderCore.kicad_sch, KludgeSpace.kicad_sch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]
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2023-09-30 Make main schematic match V503 schematic control signal naming and minor layout cleanup
    [ALU.kicad_sch, KludgeSpace.kicad_sch, Stacks.kicad_sch]
2023-10-02 Disable sysaddr_src decoder when the Nano has control of the address bus (the Nano never disables its address transceivers when it has control)
    [ALU.kicad_sch, KludgeSpace.kicad_sch, SouthCentral.kicad_sch]
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2024-06-13 Update chiptester to match small wiring fixes from KiCad
    [Chiptester.fzz]
2024-07-18 Complete basic test vectors for L4C381. 4 units passed tests. Improve wiring for 24-pin ZIF socket. Also commit Fritzing changes in $YARC.
    [Chiptester.fzz]
2025-08-24 Fix formatting on the assembly code
